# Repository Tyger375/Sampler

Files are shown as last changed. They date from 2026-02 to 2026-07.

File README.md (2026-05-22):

# Sampler

**Abstract**\
The project consists of engineering an electronic musical sampler from scratch. The work combines hardware development with the implementation of dedicated software, creating a machine equipped with pressure-sensitive pads for managing audio samples, inspired by the history of hip-hop music. This experience, balancing hobby and education, has provided solid technical skills and is conceived to be constantly updated and perfected.

Read the paper [here](https://github.com/Tyger375/Sampler/blob/main/docs/out/out.pdf) \
*made with [btex](https://github.com/Tyger375/btex)*

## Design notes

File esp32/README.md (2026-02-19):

# ESP32

Code for ESP32\
Contains:
- USB communication with slave
    - MIDI
    - CDC (Logger)
    - Vendor
- LCD 16x2 graphics
- Quantizer
- Drumpad mode
- Sequencer mode

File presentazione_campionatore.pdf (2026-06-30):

## Progettazione e Creazione di un Campionatore Elettronico

Edoardo Takanen

IIS Archimede

Edoardo Takanen (IIS Archimede) | Progettazione e Creazione di un Campionatore Elettronico | 1 / 12

## Cos’`e un Campionatore

Il campionatore (in inglese sampler) (https://www.youtube.com/watch?v=zjo7jkI8mO0) `e uno strumento musicale elettronico che `e in grado di acquisire suoni in formato digitale.

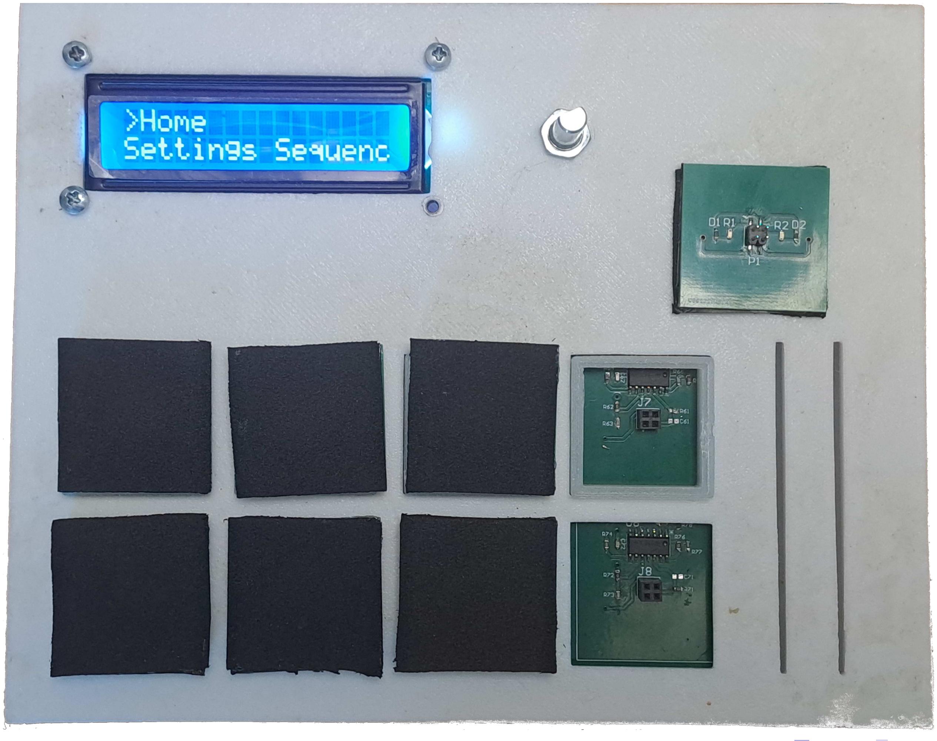
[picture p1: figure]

Edoardo Takanen (IIS Archimede) | Progettazione e Creazione di un Campionatore Elettronico | 2 / 12

## Strumentazione Utilizzata

Programmi:

KiCad
Autodesk Fusion
CLion (C++ e Rust)
MIDI-Monitor

Strumentazione e Materiali:

ESP-32 (provvisorio)
Schede elettroniche (progettate) Stagnatore + Componenti
Display LCD
Encoder rotativo
Velostat
Gomma EVA
Stampante 3D + Filamenti
(bianco e semi-trasparente)
Edoardo Takanen (IIS Archimede) | Progettazione e Creazione di un Campionatore Elettronico | 3 / 12

## Progettazione (1.0): Sensori di Pressione

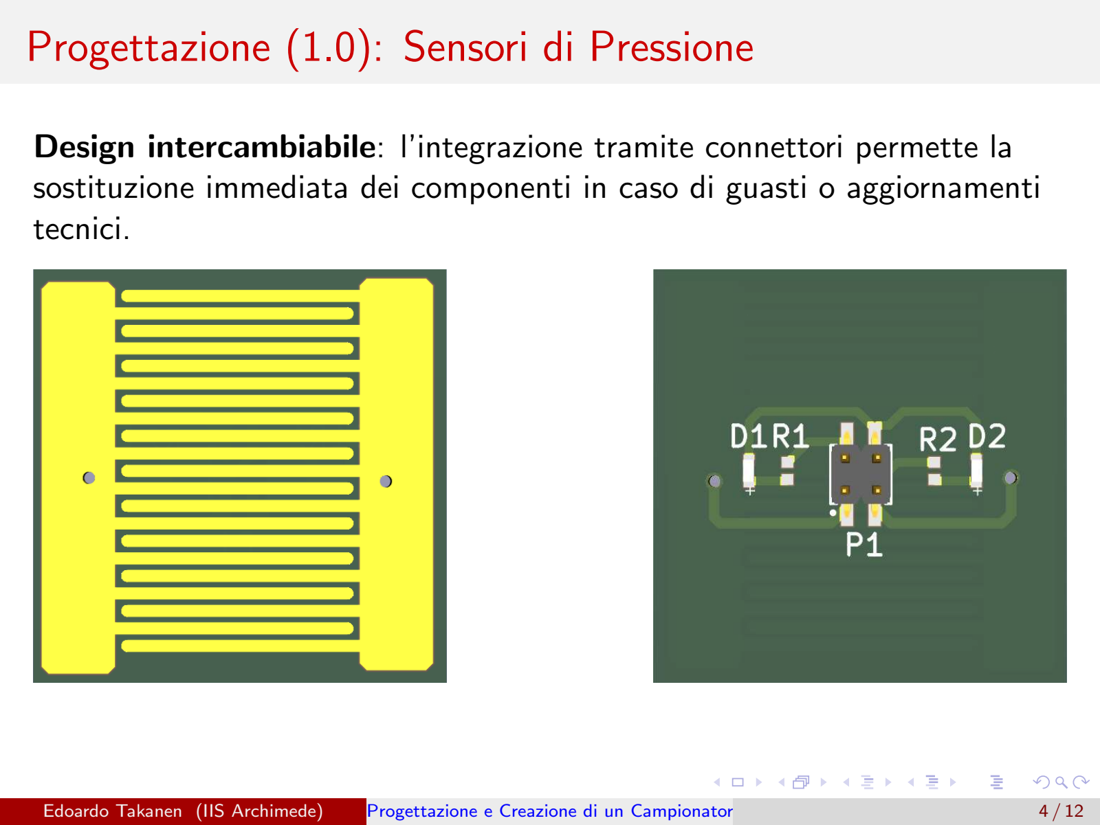
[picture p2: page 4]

Design intercambiabile: l’integrazione tramite connettori permette la sostituzione immediata dei componenti in caso di guasti o aggiornamenti tecnici.

Edoardo Takanen (IIS Archimede) | Progettazione e Creazione di un Campionatore Elettronico | 4 / 12

## Progettazione (1.1): Layering del Sensore

Il velostat a contatto con la scheda funge da resistore.
La gomma EVA ottimizza l’aderenza del sensore al pulsante.

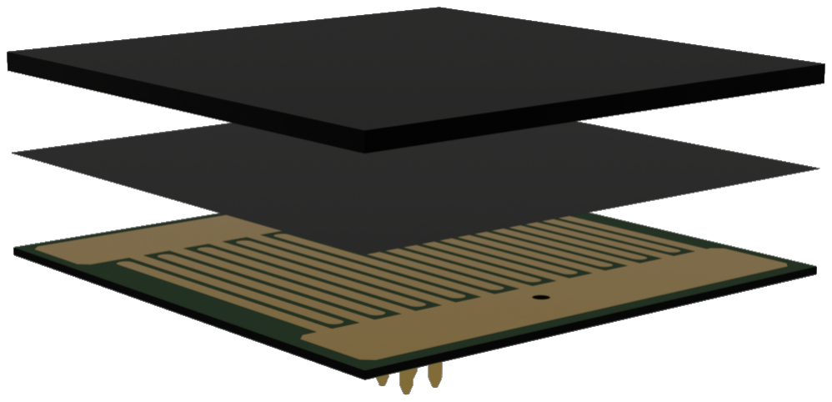
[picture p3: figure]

Edoardo Takanen (IIS Archimede) | Progettazione e Creazione di un Campionatore Elettronico | 5 / 12

## Progettazione (2.0): Supporto Sensori

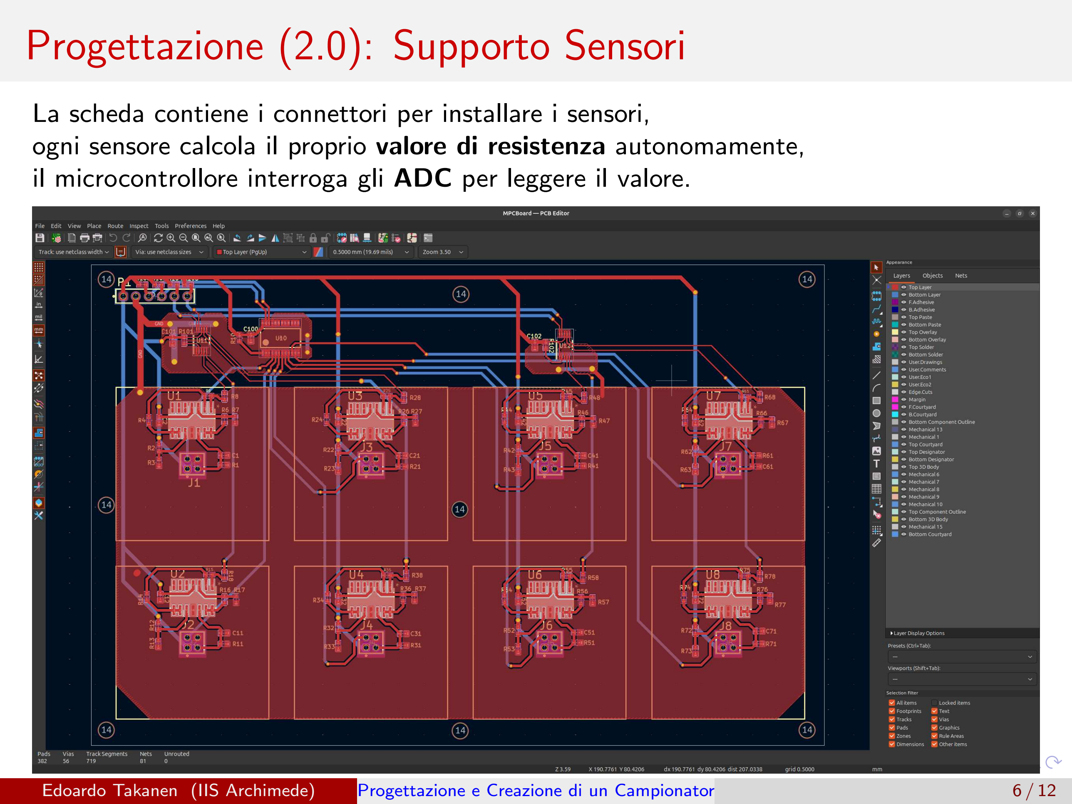
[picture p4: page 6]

La scheda contiene i connettori per installare i sensori,
ogni sensore calcola il proprio valore di resistenza autonomamente, il microcontrollore interroga gli ADC per leggere il valore.
Edoardo Takanen (IIS Archimede) | Progettazione e Creazione di un Campionatore Elettronico | 6 / 12

## Progettazione (2.1): Misurazione del valore di Resistenza

Un amplificatore da strumentazione rileva la differenza di potenziale tra i due rami del ponte di Wheatstone.

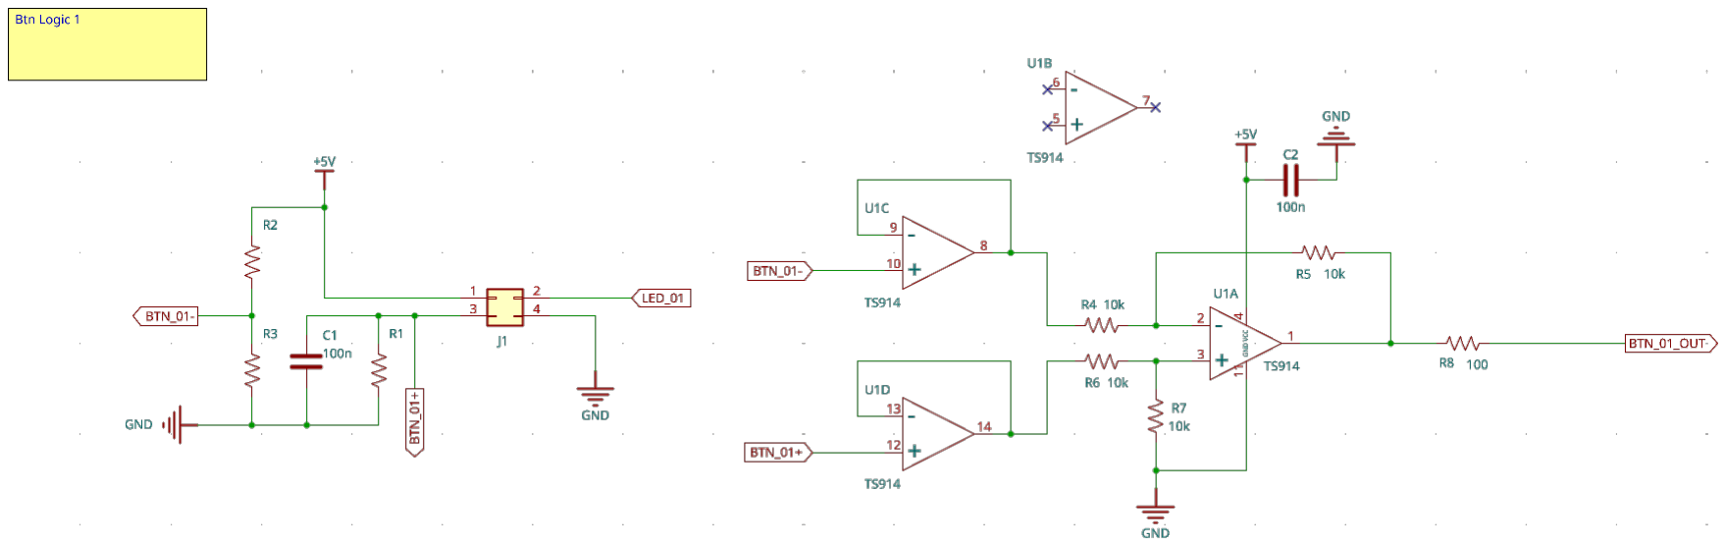
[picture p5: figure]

Edoardo Takanen (IIS Archimede) | Progettazione e Creazione di un Campionatore Elettronico | 7 / 12

## Progettazione (3.): Stampa in 3D

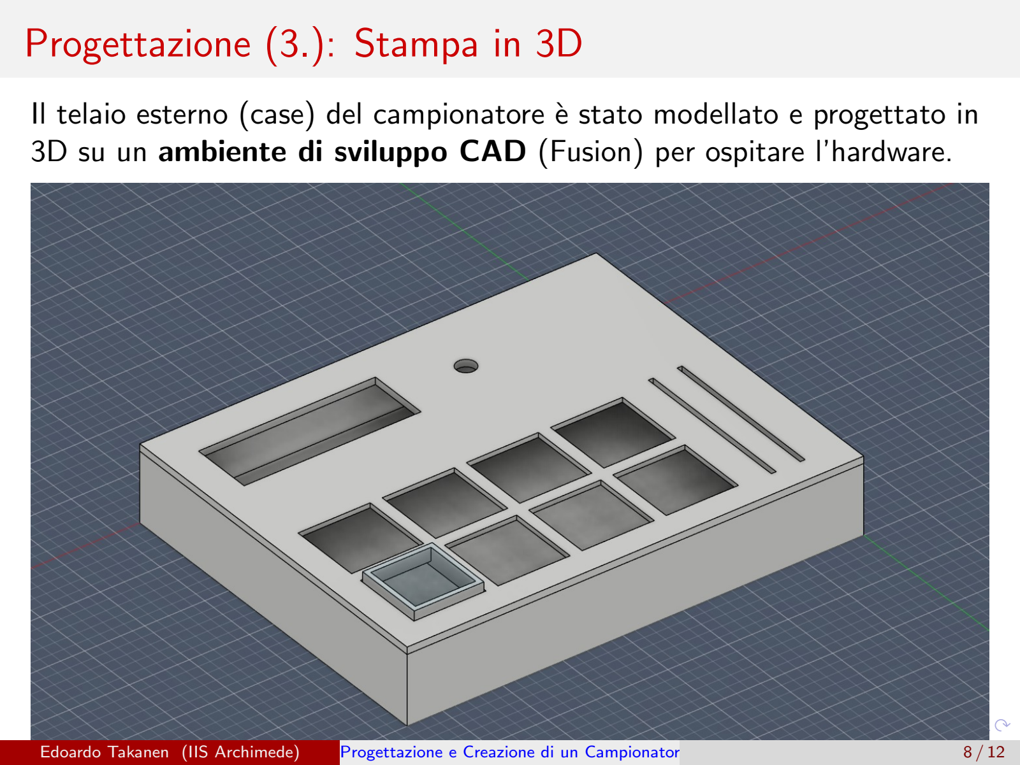
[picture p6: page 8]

Il telaio esterno (case) del campionatore `e stato modellato e progettato in 3D su un ambiente di sviluppo CAD (Fusion) per ospitare l’hardware.

Edoardo Takanen (IIS Archimede) | Progettazione e Creazione di un Campionatore Elettronico | 8 / 12

## Programmazione (4.0): Ambiente di Sviluppo

L’ESP-32 viene programmato in Rust (e C++) Gestisce:
Display LCD (I2C)
8 Pulsanti (2 ADC, I2C)
8 LED (tramite un GPIO extender, I2C)
Comunicazione USB (MIDI, CDC, Vendor) con il Master Quantizzatore
Sequenziatore
Configurazioni salvate in memoria
Edoardo Takanen (IIS Archimede) | Progettazione e Creazione di un Campionatore Elettronico | 9 / 12

## Programmazione (4.1) Il Protocollo MIDI

Ogni interazione sul controller MIDI viene convertita in un evento e inviata al Computer.
Il controller non riproduce audio, ma specifica le istruzioni musicali da far eseguire ad un sintetizzatore.

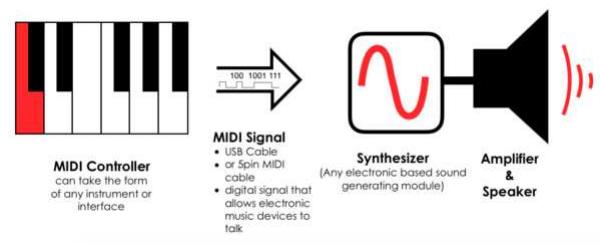
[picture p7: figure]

Edoardo Takanen (IIS Archimede) | Progettazione e Creazione di un Campionatore Elettronico | 10 / 12

## Programmazione (4.2): Quantizzatore

Allinea automaticamente le note alla griglia ritmica. Un battito (nota) `e diviso in 24 pulsazioni.

Utile per:
Sequenziatore
Sincronizzazione MIDI
Registrazione di performance
Edoardo Takanen (IIS Archimede) | Progettazione e Creazione di un Campionatore Elettronico | 11 / 12

## Programmazione (4.3): Lettura valori di pressione

Gli ADC∆Σ (Analog to Digital Converter delta-sigma) convertono costantemente i valori di resistenza.
I valori di tensione (da 0V a 5V) vengono convertiti
in valori interi a 12 bit (da 0 a 4095).
Con 3300 SPS (samples per second) una misurazione impiega circa 0.3ms.

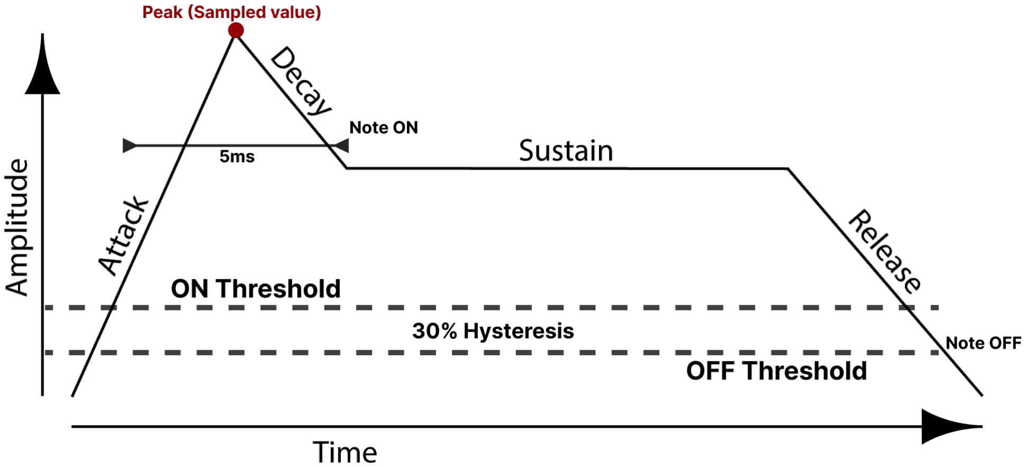
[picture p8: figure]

Edoardo Takanen (IIS Archimede) | Progettazione e Creazione di un Campionatore Elettronico | 12 / 12

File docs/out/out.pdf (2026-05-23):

# Design and Construction of a Music Sampler

Edoardo Takanen

May 23, 2026

# Introduction

A sampler is an electronic musical instrument that records and plays back samples (digital audio assets). It generally comes with a set of pressure sensitive pads, each of them can be configured to reproduce a different sample. This machine has been frequently used in hip hop music for over the past 30 years, with the Akai MPC being the most popular series of Samplers used by producers.
My goal is to engineer a custom solution from the ground up. This project was for fun as a hobby but also educational, as it required both designing the hardware and implement a dedicated software–I have learned so many new things and I definitely do not consider this project finished, but I will keep on upgrading and perfecting it.
Custom building something always comes with advantages and disadvantages. On one hand, it grants absolute control over the device, being able to implement whatever I want whenever I need some new features has a lot of different outcomes–it makes the device more flexible to future requirements. While on the other hand, there are a lot of challenges to address and options to consider, not to mention that what I am trying to imitate is something so complex that it usually takes a whole team to build–sometimes reinventing the wheel is just stressful!
Moreover, as my last year of high school, I am required to present a project that reflects my personal and technical growth throughtout this year. I believe this project fits the best for this task; compared to my previous projects, it aligns most closely with my future academic path. As I prepare to enter a five-year journey in Electronic Engineering at University, this design serves as a practical foundation for the challenges ahead.

1

## Contents

1 The Pad | 3
2 The Pads Board | 4
3 Development Tools | 6
4 Pads Management | 8
5 LedsManager | 14
6 Quantizer | 14
7 Sequencer | 18
8 Graphics | 21
9 Settings and Configurations | 25

2

## 1 The Pad

Of course the first challenge was the pressure sensitive pads. I quickly realized that there is no commercial solution that really emulates the Akai pads–my research pivoted toward custom manufacturing. I then discovered Velostat, an electrically conductive material, generally used as a packaging material, which occurs to be piezoresistive, hence, its resistance changes with pressure. Thus, each pad would consist of a PCB with exposed traces and a square of velostat pressed against the surface, the latter will connect the two traces creating a resistive path. A simple Wheatstone’s bridge will easily help us to calculate the resistance value.

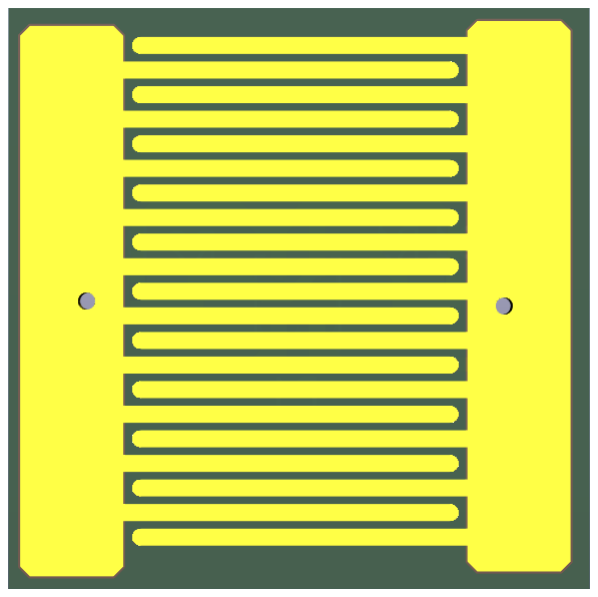
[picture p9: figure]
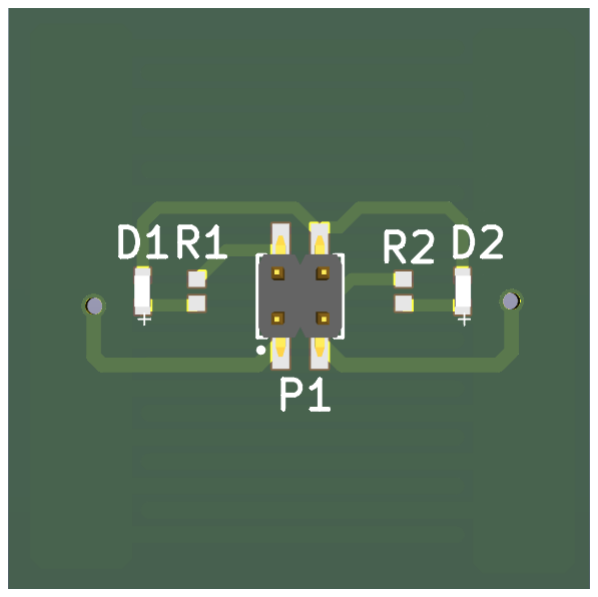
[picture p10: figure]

Furthermore, I prioritized a modular architecture. By utilizing dedicated connectors, maintenance and upgrades become seamless, allowing for the effortless replacement of individual components without affecting the entire system. Finally, I integrated LEDs to provide intuitive and instantaneous visual feedback.


The final assembly includes an uppermost layer of EVA foam, which guarantees a sufficient downward pressure to maintain solid interface between the resistive material and the conductive traces.

3

## 2 The Pads Board

After getting the pads manufactured and shipped, I needed a dedicated interface board that would handle eight buttons in place. Since MCUs hardly support eight analog pins, letting a microcontroller handle individual analog value reads and LEDs is not the optimal solutions. Hence, the board integrates external ADCs communicating via the I2C protocol.
Adopting the same modular philosophy as the pads, the architecture simplifies the interface to just six connections: a single I2C line for the ADCs, separated (in order to split the load and decrease timing issues) from another I2C line for the GPIO extender, which will control LEDs, alongside two power pins.

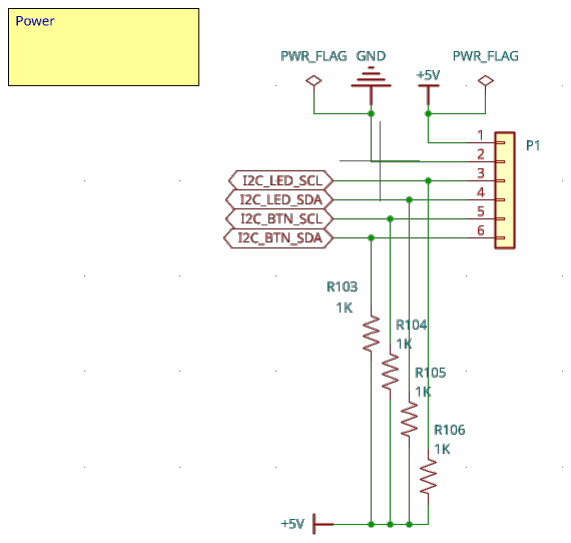
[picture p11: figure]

Figure 2: board powering

The ADS1015 is a delta-sigma analog-to-digital converter that perfectly aligns with my project requirements. With 12-bit resolution, four singleended inputs and a sampling rate of up to 3300 SPS, this component embodies all the qualities I was looking for–high convertion speed (one convertion takes approximately 0.3ms), a decent resolution (unsigned integers up to 4095) and its ability to handle four inputs via a single I2C address makes it a cost-effective and space-efficient solution for multi-channel sensing.
A Wheatstone’s bridge-based approach outputs differential signals, which the ADS1015 does support; however, this reduces the capacity to only two inputs per converter. Scaling this to eight buttons would force us to use four separate ADCs, heavily increasing delays and causing a communication bottleneck, due to the fact that they all would need to share a single I2C line. To resolve this issue, the differential signal must be processed externally before reaching the ADC. While dedicated instrumentation amplifiers are ideal for this task, as they contain low-tolerance internal resistors, which obviously means a higher unit cost. Consequently, I figured out that emulating the instrumentation amplifier myself using three common operational amplifiers was a cheaper so-

4

lution, sacrificing an ultra-high sensing precision, which was not significant for this project.
More convenient was in fact the TS914, which packages four rail-to-rail opamps, which let us keep tidiness on the board, furthermore isolating each pad, decreasing PCB complexity and maintaining a clean layout.

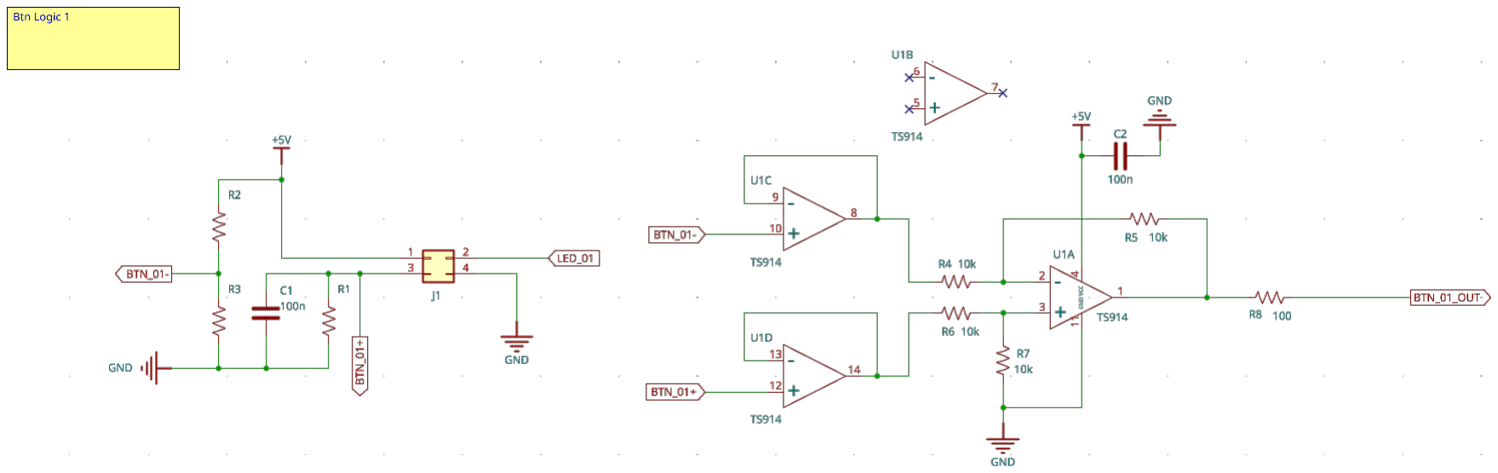
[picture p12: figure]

Figure 3: signal processing structure

Figure 3 represents the complete signal processing chain for a single pad; this architecture was subsequently replicated across all eight inputs.

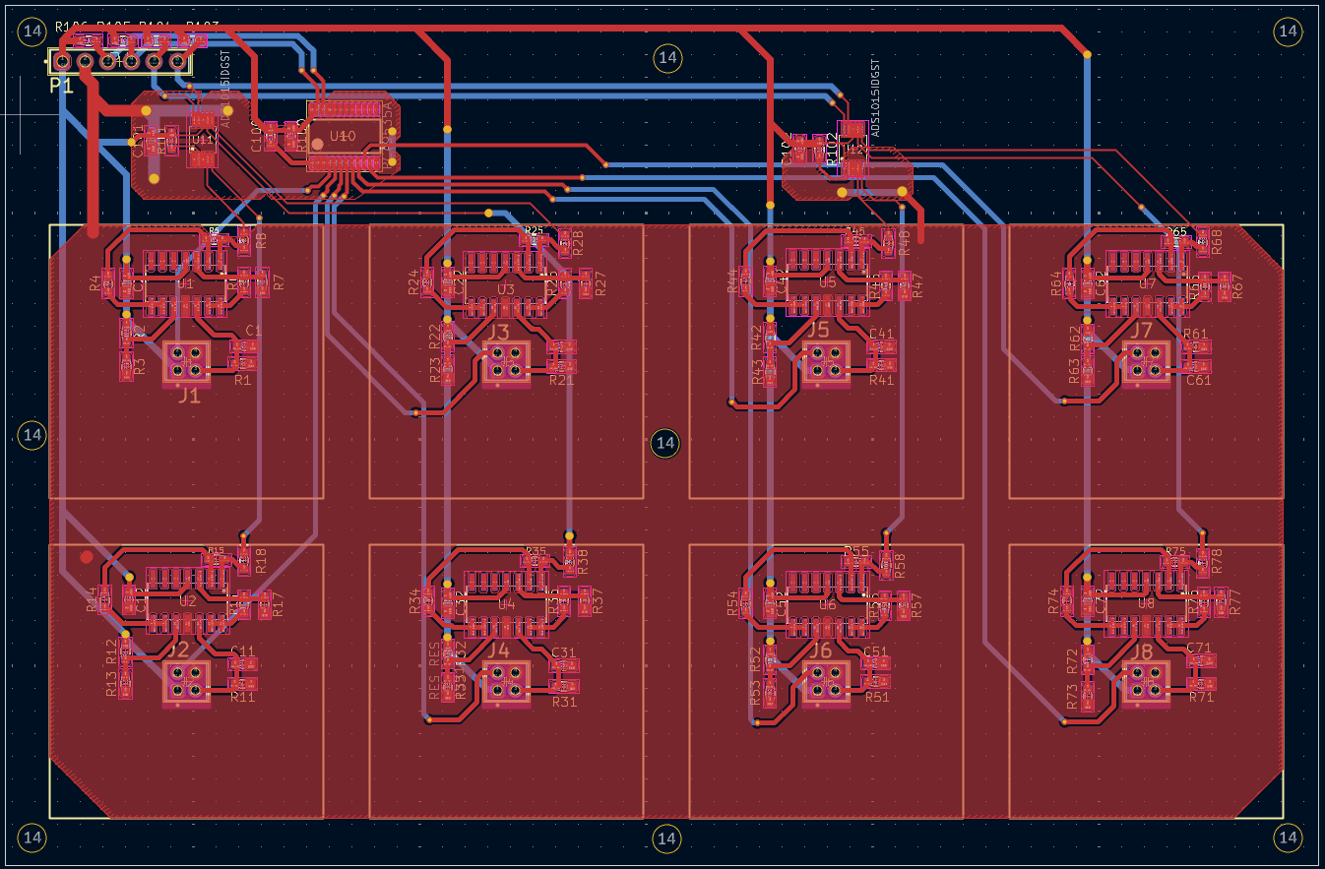
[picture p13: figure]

Figure 4: board PCB

As mentioned before, when designing the PCB, I focused on simplicity and maintaining a clean layout. Each pad is allocated a dedicated zone on the board, all the components are contained within that footprint, giving a clear visual representation of independency and isolation I was referring to.
Further information can be found inside the GitHub repository. All KiCad schematics and PCB layout fiels have been released as open-source material.

5

## 3 Development Tools

As already mentioned above, this board cannot work independently, it does not contain any processing unit that could elaborate the converted signals. Therefore this project will require another PCB to manage overall functionality of the sampler. At the time of this first draft of the paper, I still have yet to design such board, in which I plan to implement devices to allow standalone functionalities, so that no additional hardware (computers or MIDI synthesizers) is required for the instrument to work, like professional samplers.
Until the development of this final board, the only way to experiment with everything that was printed so far was to set up a breadboard environment, using an Arduino Nano ESP32 I had at home. Having already some experience with esp32 devices and their development kit, I chose the esp32s3 (the chip installed in the Arduino Nano ESP32) as a final choice for the board. Hence, the development started as a C++ project using the official espressif esp-idf framework.
Unintentionally, during this development period I was also interested in the Rust programming language and started reading the official book (https://doc.rust-lang.org/book/) just for fun and out of curiosity. I became deeply fond of the language; despite to Rust’s strict yet principled rules, transitioning from C++ was challenging but ultimately allowed me to write safer and more predictable code. As a result, I decided to utilize Rust for a real-world project for the first time. Adapting to a completely different programming language philosophy–especially Rust’s paradigm, which differs drastically from most languages–was not a seamless process, and I have yet to master it completely. Nevertheless, it proved to be an incredibly rewarding and exciting challenge, and I fully intend to continue experimenting with the language in the future.
In the GitHub repository, I decided to keep both versions of the software (folders esp32 and esp32 rust).
I opted for the esp-rs/esp-idf (https://github.com/esp-rs/esp-idf-hal) hardware abstraction layer, which does include Rust’s standard library but is not carried on officially by espressif, but rather by the community. As a result, some C++ libraries might not have been ported to Rust yet, which makes it difficult to completely migrate from C++ to Rust. This was the case for TinyUSB, an important library I was relying on to declare a composite USB device recognisable by the computer.
To fix this issue, I chose to follow esp-idf template’s (https://github.com/esp-rs/esp-idf-template) way of mixing C++ and Rust, which suggests to keep the official’s idf.py tools and C++, with the addition of a Rust static library. By using this method, I can still include esp-idf’s C++ libraries and expose methods to the Rust library, covering for what Rust’s unofficial framework has not implemented yet.

6

Thus, you can find a single C++ file that initializes USB capabilities using TinyUSB and exposes some of its functions to Rust.

1 // midi .rs

2
3 | extern "C" {
4 | // C++ defined functions
5 | fn midi_mounted () -> bool ;
6 | fn midi_out ( packet : * const [u8; 4]) ;
7 | }

8
9 pub struct MIDI ;

10
11 | // Wrapping unsafe methods
12 | impl MIDI {
13 | pub fn send ( packet : &[ u8; 4]) {
14 | unsafe {
15 | if midi_mounted () {
16 | midi_out ( packet ) ;
17 | }
18 | }
19 | }
20 | }

A primary focus during the software architecture design was achieving a high level of abstraction. Because this project is intended to be an evolving platform for long-term development, the ability to seamlessly modify and upgrade parts of the code was a must (thus, keeping that modular philosophy for both hardware and software design). Throughtout this paper, it will become evident how the codebase is divided into independent, decoupled ’libraries’– separating graphical rendering, system settings, and hardware configurations to maximize maintainability.

7

## 4 Pads Management

### 4.1 ADC Driver

As already mentioned, the pads board needs an MCU to configure the ADCs and read those resistance values. For starters, an ADS1015 driver needed to be developed. Module ads1015/mod.rs contains all the enums and methods to access and configure the ADCs via I2C communication.

1 | pub struct ADS1015 {
2 | i2c : Arc <Mutex < I2cDriver <’ static > >>,
3 | cfg_reg : AtomicU16 ,
4 | addr : u8 ,
5 | }

6
7 | impl ADS1015 {
8 | pub fn new (
9 | i2c : Arc <Mutex < I2cDriver <’ static > >>,
10 | addr : u8
11 | ) -> Self {
12 | ADS1015 {
13 | i2c ,
14 | cfg_reg : AtomicU16 :: new (0) ,
15 | addr ,
16 | }
17 | }
18 | // ...
19 | pub fn read (& self ) -> u16 {
20 | const REG_ADDR : [u8; 1] = [0 x0 ];
21 | let mut data : [u8; 2] = [0 , 0];

22
23 | {
24 | if let Ok( mut guard ) = self . i2c . lock () {
25 | guard
26 | . write_read (
27 | self . addr , & REG_ADDR , &mut data , 1000
28 | )
29 | . unwrap () ;
30 | }
31 | }

32
33 | let raw_val = (( data [0] as u16 ) << 8) | ( data [1] as u16 );
34 | raw_val >> 4
35 | }
36 | }

Recall that the two ADCs share a single I2C line, therefore, the I2cDriver also needs to be shared, which can be done safely by wrapping the struct in a std::sync::Mutex. The ADS1015 structure was designed to work securely in multi-threading environments–the only mutable variable is marked as an Atomic and all the structure’s methods work adopting the interior mutability pattern. Listing 4.1 shows how the read method fetches the latest converted value.

8

### 4.2 Pads Manager

Following with the PadsManager structure, responsible for the actual ADCs handling and reading. The instantiator creates two ADCs variables with the same configuration; the multiplexer is set to convert the first channel first, FSR (full-scale range) and data-rate are set to their maximum values, corresponding to ±6.144V (which is clamped to 5V, the supply voltage) and 3300 SPS (samples per second). The operating mode is obviously set to continuous, while the comparator is disabled.

1 | let i2c_config = I2cConfig :: new () . baudrate ( Hertz (400 _000 ));
2 | let i2c_master = I2cDriver :: new ( i2c , sda , scl , & i2c_config ) ?;

3
4 let i2c_bus = Arc :: new ( Mutex :: new ( i2c_master ) );

5
6 | let ads_cfg = ADS1015Config {
7 | mux_config : MuxConfig :: MUX0 ,
8 | fsr_mode : Fsr6_144 ,
9 | op_mode : OpModeConfig :: Continuous ,
10 | data_rate : DataRateConfig :: DataRate3300 ,
11 | comparator_mode : CompModeConfig :: Traditional ,
12 | comparator_polarity : CompPolarityConfig :: ActiveLow ,
13 | comparator_latching : CompLatchingConfig :: NonLatching ,
14 | queue_and_disable : CompQueueDisableConfig :: DisableComp ,
15 | };

16
17 | let ads1 = ADS1015 :: new ( i2c_bus . clone () , addr1 );
18 | let ads2 = ADS1015 :: new ( i2c_bus . clone () , addr2 );

19
20 | ads1 . set_config (& ads_cfg ) ?;
21 | ads2 . set_config (& ads_cfg ) ?;

9

### 4.3 Sensing Task

PadsManager’s main functionality is it’s internal task.

1 | /*
2 | name : " pads_input_task ",
3 | stack_size : 4096 ,
4 | priority : 15 ,
5 | pin_to_core : Some ( Core0 ),
6 | */

7
8 let mut channel : usize = 0;

9
10 | loop {
11 | delay_us (750) ;

12
13 | let value1 = ads1 . read () ;
14 | let value2 = ads2 . read () ;

15
16 | if let Some ( item ) = process_pad_physics ( channel as u8 , & mut
| pads_settings [ channel ], value1 ) {
17 | queue . send_back ( item , 0) . unwrap () ;
18 | };

19
20 | if let Some ( item ) = process_pad_physics (( channel as u8) + 4, &
| mut pads_settings [ channel + 4] , value2 ) {
21 | queue . send_back ( item , 0) . unwrap () ;
22 | };

23
24 | channel = ( channel + 1) % 4;

25
26 | let cfg = MuxConfig :: mux_from ( channel as u8);
27 | ads1 . set_mux (& cfg ). unwrap () ;
28 | ads2 . set_mux (& cfg ). unwrap () ;
29 | }

This is the heart of the pad sensing task (debug symbols were removed for simplicity). A task with relatively high priority (15) is pinned to the processor’s Core0 and continuously fetches ADC values and sends events to another task using FreeRTOS’s Queue.
Since a single conversion takes 0.3ms, switching channels on the multiplexer needs some time, a delay is added to prevent incorrect data from previous conversions. Switching multiplexer channels and readings from both ADCs is done almost simultaneously to save time, eight pad measurements take around 1.2ms. Moreover, software correction accounts for hardware inaccuracy and enhances the experience.

10

1 | fn process_pad_physics ( index : u8 , settings : &mut DrumPad , value :
| u16 ) -> Option < PadInputEvent > {
2 | let now = timestamp () ;
3 | const SCAN_TIME_MS : u32 = 5;
4 | const RETRIGGER_MASK_MS : u32 = 30; // Helps to debounce by
| removing noise

5
6 | match settings . state {
7 | PadState :: Idle => {
8 | if value > settings . threshold {
9 | settings . state = PadState :: Attack ;
10 | settings . peak = value ;
11 | settings . timer_start = now ;
12 | }
13 | None
14 | }
15 | PadState :: Attack => {
16 | // Update peak if sample is higher
17 | if value > settings . peak {
18 | settings . peak = value ;
19 | }

20
21 | // Wait 5ms
22 | if now - settings . timer_start >= SCAN_TIME_MS {
23 | settings . state = PadState :: Sustain ;

24
25 | let velocity = ( settings . peak >> 5) . min (127) as u8;

26
27 | Some ( PadInputEvent {
28 | index ,
29 | channel : settings . channel ,
30 | note : settings . note ,
31 | velocity : velocity ,
32 | event_type : PadInputEventType :: MIDI ( MidiType ::
| NoteOn ) ,
33 | })
34 | } else {
35 | None
36 | }
37 | }
38 | PadState :: Sustain = > {
39 | // Look for the value to drop below threshold
40 | const HYSTERESIS : f32 = 0.7;
41 | if value < ( settings . threshold as f32 * HYSTERESIS ) as
| u16 {
42 | settings . state = PadState :: Release ;
43 | settings . timer_start = now ;

44
45 | Some ( PadInputEvent {
46 | index ,
47 | channel : settings . channel ,
48 | note : settings . note ,
49 | velocity : 0,
50 | event_type : PadInputEventType :: MIDI ( MidiType ::
| NoteOff ) ,
51 | })
52 | } else {

11

53 | None
54 | }
55 | }
56 | PadState :: Release = > {
57 | if now - settings . timer_start >= RETRIGGER_MASK_MS {
58 | settings . state = PadState :: Idle ;
59 | }

60
61 | None
62 | }
63 | }
64 | }

One pad press goes throught four different stages.

1. When the state is on Idle, the program waits for a value to go above a certain threshold, which can be configured individually for each pad.
2. From that moment, the program enters the Attack state–a 5ms window is opened to look for the highest value, which will be used as the pad velocity, a NoteOn event is sent, consequently a MIDI event is transmitted to the USB host.
3. After that, the Sustain state starts, the function waits for a value to go below 70% of the configured threshold (allowing a 30% of hysteresis), a NoteOff event is sent, followed by a MIDI event.
4. Finally, the Release state waits 30ms for debouncing, preventing the pad to retrigger instantly.

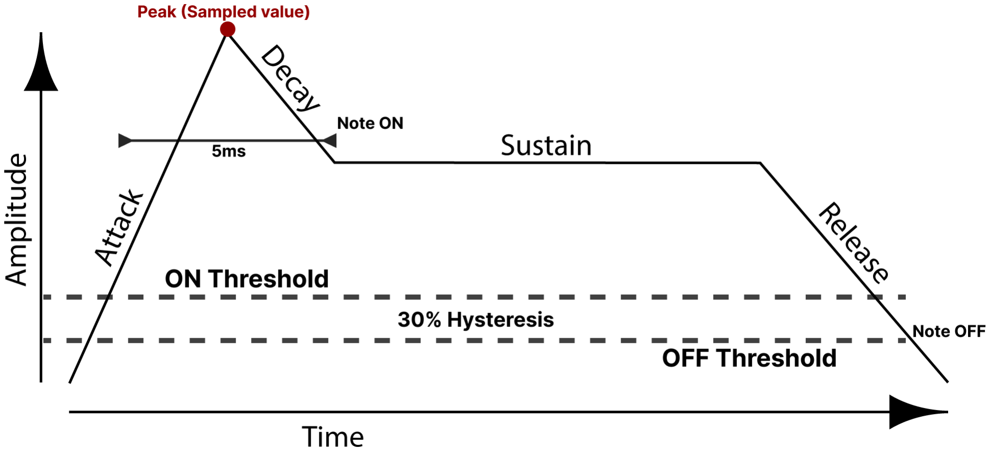
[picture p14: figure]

Figure 5: Software pads processing

12

### 4.4 Sending MIDI Events

Events that are sent to the queue are consumed by another task with a higher priority, which sends final MIDI events to the USB host, and also controls LEDs for the pads. Again, debug symbols were removed for simplicity.

1 | /*
2 | name : " pads_midi_task ",
3 | stack_size : 4096 ,
4 | priority : 23 ,
5 | pin_to_core : Some ( Core :: Core0 ),
6 | */

7
8 | loop {
9 | if let Some (( packet , _)) = queue . recv_front ( delay :: BLOCK ) {
10 | match packet . event_type {
11 | PadInputEventType :: MIDI ( midi_type ) => {
12 | let midi : (u8 , u8) = midi_type . into () ;

13
14 | if !paused . load ( Ordering :: Relaxed ) {
15 | let bytes : [u8; 4] = [ midi .0 , midi .1 | ( packet .
| channel & 0 x0F ) , packet . note , packet . velocity ];
16 | MIDI :: send (& bytes );
17 | }

18
19 | if let MidiType :: NoteOn = midi_type {
20 | leds_manager . set_led ( packet . index , true );
21 | } else if let MidiType :: NoteOff = midi_type {
22 | leds_manager . set_led ( packet . index , false );
23 | }
24 | }
25 | // ...
26 | }
27 | };
28 | }

This code enables a ’free mode’ for the drum pads, where pressing different pads sends configurable MIDI notes to the computer. By using a software sampler like TX16Wx, these MIDI events can be used to trigger and play back digital samples.

13

## 5 Quantizer

Currently, the system sends MIDI events as soon as a pad strike is sensed, ignoring the specific timing of the press. While this works for live performances, features like recording or sequencing require the program to quantize these events. By implementing a quantizer, the software can snap the timing of each note to a grid, ensuring the performance stays in sync with a set tempo. To achieve this, we define the smallest unit of time as a pulse. In a standard 4/4 time signature, a loop is divided into four beats, represented by the metronome clicks. Standard pulse resolutions typically range from 24 to 940 PPQ, pulses (or ticks) per quarter note, where a ’quarter note’ corresponds to what we earlier defined as a beat. For the development of the quantizer, it is practical to introduce an intermediate subdivision by dividing each beat (or quarter note) into four steps (1/16th notes).

Figure 6: The quantizer grid

In figure 6 the timing quantities defined by the bigger lines are the beats. Each beat is then divided into a specific PPQ amount of intervals, while the smaller lines represent what we previously called steps.
The Quantizer struct keeps count of these steps:
1 | pub struct Quantizer {
2 | pub ticks : Arc < AtomicU8 >,
3 | pub steps : Arc < AtomicU8 >,
4 | timer : TimerDriver < ’static >
5 | }

To make the system thread-safe, these shared variables are wrapped inside Arc<AtomicU8>. This atomic wrapper is crucial because it allows safe, concurrent access and modification across both the high-frequency hardware timer interrupt handler and the asynchronous quantizer main task, preventing data races without the heavy overhead of standard mutexes in an ISR (Interrupt Service Routine).
To reach a high level of precision, I am relying on the ESP32’s hardware general purpose timer. The quantizer constructor prepares the initial timing states as well as the basic configurations for this timer. To ensure the clock remains stable even when the CPU is busy with graphics or I2C communication, the highest interrupt priority is allocated to it. The base clock resolution is configurable inside the code and is tipically configured in the MegaHertz range.

14

1 | impl Quantizer {
2 | pub fn new ( notifier : Arc < Notifier >) -> Result <Self , EspError > {
3 | let ticks = Arc :: new ( AtomicU8 :: new ( TICKS_PER_STEP - 1) ) ;
4 | let steps = Arc :: new ( AtomicU8 :: new (15) );

5
6 | let mut timer_conf = TimerConfig :: default () ;
7 | timer_conf . clock_source = ClockSource :: Default ;
8 | timer_conf . direction = CountDirection :: Up ;
9 | timer_conf . resolution = Hertz ( TIMER_RESOLUTION );
10 | timer_conf . intr_priority = 3;

11
12 | let mut timer = TimerDriver :: new (& timer_conf ) ?;
13 | timer . subscribe_default () ?;
14 | timer . enable () ?;

15
16 | // ... timer interrupt

17
18 | timer . start () ?;

19
20 | Ok( Quantizer {
21 | ticks ,
22 | steps ,
23 | timer
24 | })
25 | }
26 | }

The hardware timer does not start immediately when the quantizer is instantiated because it waits for a valid BPM value to be supplied. The main software loop is responsible for retrieving this information–either loading it from a local file configuration at boot or receiving a real-time update from the display task– and passing it to the quantizer by invoking the start method. At this point, we calculate the required pulse interval (the timer step) in microseconds using the following formula:

T IMER ST EP =

60 × T IMER RESOLUT ION
BPM × P P Q | (1)

The hardware timer will thus trigger its interrupt exactly once every pulse, creating a rock-solid master clock based on the user-configurable BPM value and the chosen PPQ resolution.

1 | impl Quantizer {
2 | pub fn start (& self , bpm : u8) -> Result <() , EspError > {
3 | let time = 60 u64 * TIMER_RESOLUTION as u64;
4 | let ticks = bpm as u64 * PPQ as u64;
5 | let timer_step = time / ticks ;
6 | self . timer . set_alarm_action ( Some (& AlarmConfig {
7 | alarm_count : timer_step ,
8 | auto_reload_on_alarm : true ,
9 | reload_count : 0,
10 | .. Default :: default ()
11 | }) ) ?;
12 | Ok (() )
13 | }
14 | }

15

Note: All these parameters can be adjusted dynamically either directly from the configuration files or using the installed LCD display; we will cover the graphics engine and screen implementation later in this paper.
For simplicity, I decided to break down the timer counting into ticks (pulses) and steps, dividing a quarter note into four steps.
1 | timer . subscribe ( move |_| {
2 | let t = ticks . fetch_add (1 , Ordering :: SeqCst );
3 | if t + 1 >= TICKS_PER_STEP {
4 | ticks . store (0 , Ordering :: Relaxed ) ;
5 | let s = ( steps . load ( Ordering :: SeqCst ) + 1) % 16;
6 | steps . store (s , Ordering :: SeqCst );
7 | }

8
9 | notifier . notify_and_yield ( NonZero :: new (1) . unwrap () );
10 | }) ?;
TICKS PER STEP is just PPQ divided by 4 .
Since we are in an interrupt context, the routine needs to be quick and nonblocking. An interrupt-safe Notifier structure is used to wake up another high-priority task.
1 | /*
2 | name : " quantizer_task ",
3 | stack_size : 4096 ,
4 | priority : 24 ,
5 | pin_to_core : Some ( Core :: Core1 ),
6 | */
7 | let notification = Notification :: new () ;
8 | let quantizer = Arc :: new ( Quantizer :: new ( notification . notifier () ).
| expect (" Failed to create quantizer ") );

9
10 | const MIDI_SYNC_STEPS : u8 = PPQ / 24;
11 | const MIDI_SYNC_MSG : [u8; 4] = [0 x0F , 0 xF8 , 0 x00 , 0 x00 ];

12
13 | loop {
14 | notification . wait_any () ;
15 | if midi_sync_step == 0 {
16 | MIDI :: send (& MIDI_SYNC_MSG );
17 | }
18 | midi_sync_step = ( midi_sync_step + 1) % MIDI_SYNC_STEPS ;

19
20 | let ticks = quantizer . ticks . load ( Ordering :: SeqCst );
21 | let steps = quantizer . steps . load ( Ordering :: SeqCst );

22
23 | // notifying the quantizer
24 | if ticks == 0 {
25 | quantizer_seq_tx
26 | . send ( SequencerMessage :: NoteOn ( steps )). ok () ;
27 | } else if ticks == 5 {
28 | quantizer_seq_tx
29 | . send ( SequencerMessage :: NoteOff ( steps )) . ok () ;
30 | }
31 | }
A good practice when creating a MIDI device is to send a MIDI synchronization packet. This is a System Real-Time message used to synchronize all the

16 connected equipment. It is a single byte status message (it does not contain any data) and it must be sent 24 times per quarter note, hence it does not depend on our configured PPQ.
notification.wait any() blocks the thread and waits for a notification from the interrupt, representing a pulse being triggered. After that, a MIDI sync message is transmitted every P P Q ÷ 24 quantizer ticks and, as we will discuss later, a sequencer message is sent at the beginning (when ticks are equal to 0) and ending (last tick before a new step) of every step.

17

## 6 Sequencer

A sequencer enables the recording of a musical performance by capturing and storing note triggers relative to a master timeline. By mapping these events to specific timestamps, the sequencer can accurately reproduce the performance with consistent rhythmic integrity.
You can think of a sequencer performance as FL Studio’s channel rack, each instrument has a different programmed pattern which repeats endlessly.

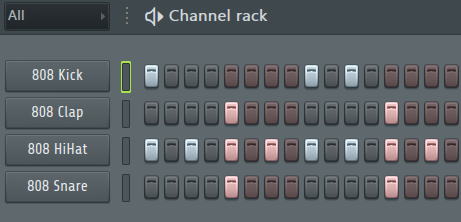
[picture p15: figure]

Figure 7: FL Studio’s Channel Rack

Thus, a sequencer project is structured as a list of tracks.

1 | pub struct SequencerTrack {
2 | pub loops : u8 ,
3 | pub resolution : SequencerResolution ,
4 | pub note : u8 ,
5 | pub triggers : Vec <u8 >,
6 | }

7
8 | pub struct SequencerProject {
9 | pub name : String ,
10 | pub loops : u8 ,
11 | pub tracks : Vec < SequencerTrack >
12 | }
While earlier we defined the largest unit of time as a loop, containing four quarter notes, a sequencer performance allows for more complex patterns with multiple loops. Each track has its own loops count, we do not need to program for four loops a simple hi-hat 2-step pattern, simply setting the project loop to 4 and track loop to 1 will do the trick. Obviously, track loop needs to be a multiple of project loop.
Notes can be programmed using the eight pads, when the Sampler is set to track programming mode, the pads LEDs stay on for set triggers, while project and tracks configurations can be edited from their screens. Since only eight pads for

18 a sequencer might not be ideal, I added a resolution parameter to each track. Resolutions range from each note representing a whole loop note, to represent a single quarter note.

1 | pub enum SequencerResolution {
2 | Quarter | = 1,
3 | HalfBeat | = 2,
4 | Beat | = 4,
5 | Loop | = 16 ,
6 | }

Mind that in this context, quarter notes and beats are not used as synonyms–I defined quarter notes as a quarter of a beat (1/16th of a loop).
The sequencer is handled by another high-priority task, which constantly waits for messages sent by the quantizer using Rust’s std::sync::mpsc::channel().
1 | /*
2 | name : " sequencer_task ",
3 | stack_size : 4096 ,
4 | priority : 23 ,
5 | pin_to_core : Some ( Core :: Core1 ),
6 | */
7 | loop {
8 | if let Ok( item ) = sequencer_channel . recv () {
9 | if sequencer . enabled () {
10 | match item {
11 | SequencerMessage :: NoteOn ( step ) => {
12 | sequencer . step_trigger_on ( step );
13 | }
14 | SequencerMessage :: NoteOff ( step ) = > {
15 | sequencer . step_trigger_off ( step );
16 | }
17 | }
18 | }
19 | }
20 | }

From this moment, the sequencer handles the triggers.

1 | pub fn step_trigger_on (& self , step : u8) {
2 | // ...
3 | for ( track , state ) in project . tracks . iter () . zip ( guard . iter_mut
() ) {
4 | let track_step = step + (16 * ( current_loop % track . loops ))
| ;
5 | Self :: handle_track_on ( track , track_step , state );
6 | }
7 | }
8 | fn handle_track_on ( track : & SequencerTrack , step : u8 , state_trigger :
| & mut bool ) {
9 | for trigger in track . triggers . iter () {
10 | let real_trigger = trigger * ( track . resolution as u8) ;
11 | if real_trigger == step {
12 | * state_trigger = true ;
13 | MIDI :: send (&[0 x09 , 0 x90 , track . note , 127]) ;
14 | }
15 | }
16 | }

19

17
18 | pub fn step_trigger_off (& self , step : u8) {
19 | // ...
20 | for ( track , state ) in project . tracks . iter () . zip ( guard . iter_mut
() ) {
21 | let track_step = step + (16 * ( current_loop % track . loops ))
| ;
22 | Self :: handle_track_off ( track , track_step , state );
23 | }

24
25 | if step == 15 {
26 | self . current_loop . store (( current_loop + 1) % project . loops ,
| Ordering :: Relaxed ) ;
27 | }
28 | }
29 | fn handle_track_off ( track : & SequencerTrack , step : u8 , state_trigger
| : & mut bool ) {
30 | for trigger in track . triggers . iter () {
31 | let real_trigger = (( trigger + 1) * ( track . resolution as u8
| )) - 1;
32 | if real_trigger == step {
33 | * state_trigger = false ;
34 | MIDI :: send (&[0 x08 , 0 x80 , track . note , 0]) ;
35 | }
36 | }
37 | }

Since track triggers are saved as pads indexes, before checking if a MIDI packet should be sent, the trigger value must be converted as a relative trigger.

Figure 8: A quantizer project example

Figure 8 shows an example of a one loop project with two tracks, emulating a simple 2-step hi-hat and snare pattern. The hi-hat pattern represented with red steps is configured with a resolution of HalfBeat and by triggering every single sequencer step on the drumpad. The snare pattern is shown colored in blue and is configured with a Beat resolution and by triggering the third pad on the first row of the drumpad.

20

## 7 Graphics

The most complex library I have written in this project is definitely the part that handles graphics. When designing such library, I aimed at some ’high’ level abstraction which would separate hardware communication from UI composition. A lot of inspiration was taken from Android’s (now) old style of building UIs and Applications–Android XML.
At the moment, I am using a text-based 16x2 LCD display, thus, the graphics library heavily relies on Rust’s String structure.
The GraphicsManager is the core of this graphics library, this structure stores screen instantiators, installs graphics drivers and handles graphics Events.
1 | pub struct GraphicsManager <’a > {
2 | drivers : Vec <Box < dyn GraphicsDriver >> ,
3 | screens_factories : HashMap <& ’ a str , Box < dyn Fn( ScreenArgs ) ->
| Box < dyn Screen >>>,
4 | current_screen : Option <(& ’ a str , Box < dyn Screen >) >,
5 | backstack : Vec <& ’ a str >
6 | }

This graphics set of utilities relies on graphics Events, a screen is only refreshed when an update is sent. Events are sent from hardware controls, like pads pressing, controller movements etc.

1 | pub enum GraphicsEvent {
2 | Click ,
3 | Back ,

4
5 | ScrollLeft ,
6 | ScrollRight ,

7
8 | ScreenStart ,
9 | ScreenEnd ,

10
11 | Refresh ( String )
12 | }

Graphics events are sent by the graphics manager to the current screen, which will dispatch them to the focused UIElement.

21

### 7.1 Screen

UIs are built on screens, which can be compared to Android’s Activities. Default method implementations are omitted for simplicity.

1 | pub struct ScreenData {
2 | pub elements : Vec <Box < dyn UIElement >>,
3 | pub row_offset : usize ,
4 | pub focus : bool
5 | }

6
7 | pub trait Screen {
8 | fn get_data (& self ) -> & ScreenData ;
9 | fn get_data_mut (& mut self ) -> & mut ScreenData ;

10
11 | fn on_start (& mut self );
12 | fn on_end (& mut self );

13
14 | fn on_click (& mut self );
15 | fn on_back (& mut self ) -> bool ;
16 | fn on_scroll (& mut self , direction : bool );

17
18 | fn on_custom_event (& mut self , _event : u32 ) -> bool ;

19
20 | fn refresh (& mut self , _message : String ) ;
21 | fn render (& self , selector_press : bool ) -> Vec < String >;
22 | }

A screen can contain different UIElements, like texts, buttons etc.
At startup, the main thread loads the GraphicsManager with all the screen instantiators (initializers). The instantiators are summoned when required.
1 | pub fn load_screen <F >(& mut self , id: &’a str , factory : F )
2 | where F: Fn( ScreenArgs ) -> Box < dyn Screen > + ’static {
3 | self . screens_factories . insert (id , Box :: new ( factory )) ;
4 | }

5
6 | fn navigate_screen (& mut self , id: &’a str , mut screen : Box < dyn
| Screen >) {
7 | if let Some ( current_screen ) = self . current_screen . as_mut () {
8 | current_screen .1. on_end () ;
9 | }

10
11 | screen . on_start () ;
12 | self . current_screen = Some ((id , screen )) ;
13 | }

14
15 | pub fn navigate (& mut self , id: &str , _args : Vec < String >) {
16 | let (id , factory ) = self . screens_factories . get_key_value (id).
| expect (" Couldn ’t find screen ");

17
18 | if let Some ( current_screen ) = self . current_screen . as_mut () {
19 | self . backstack . push ( current_screen .0) ;
20 | }

21
22 | self . navigate_screen (id , factory ( None ) );
23 | }

22

### 7.2 UIElement

A UIElement takes a whole line on the LCD, a render method returns the text to render on screen, an on event method handles events to consume graphics interactions, a boolean value is returned to specify if the component requires internal focus.

1 | pub trait UIElement {
2 | fn render (& self , state : UIElementState ) -> String ;

3
4 | fn on_event (& mut self , _event : GraphicsEvent ) -> bool {
5 | false
6 | }
7 | }

Below, the button component is reported as an example.

1 | pub struct UIButton {
2 | text : String ,
3 | on_click : Box < dyn Fn () >
4 | }

5
6 | impl UIButton {
7 | pub fn new <F >( text : String , on_click : F) -> Self
8 | where F: Fn () + ’static {
9 | UIButton {
10 | text ,
11 | on_click : Box :: new ( on_click )
12 | }
13 | }
14 | }

15
16 | impl UIElement for UIButton {
17 | fn render (& self , state : UIElementState ) -> String {
18 | let prefix = match state {
19 | UIElementState :: Selected => ">",
20 | UIElementState :: SelectorPress => "\\",
21 | UIElementState :: None => ""
22 | };
23 | format! (" {}{} ", prefix , self . text )
24 | }

25
26 | fn on_event (& mut self , event : GraphicsEvent ) -> bool {
27 | match event {
28 | GraphicsEvent :: Click => {
29 | ( self . on_click ) () ;
30 | false
31 | }
32 | _ => false ,
33 | }
34 | }
35 | }

23

### 7.3 Rendering and Graphics Drivers

As mentioned before, display refreshes are triggered only when needed. The GraphicsManager calls the current screen’s render function, which iterates throught two on-screen components and invokes their render methods. After that, the manager iterates throught installed graphics drivers and sends those returned strings for rendering.

1 | pub trait GraphicsDriver {
2 | fn init (& mut self ) ;
3 | fn draw (& mut self , rows : &Vec <String >) ;
4 | fn clear (& mut self );
5 | }

When developing this graphics library, I opted for an almost completely abstract approach, so that future changes or updates will result easy and effortless.

24

## 8 Settings and Configurations

As I mentioned earlier, one of my main goals when structuring this project was abstraction. Because I want to keep updating and expanding this project over the next few years, I couldn’t just hardcode configurations or dump everything into a single file. I needed a system where parts of the code could be seamlessly swapped or upgraded without breaking the rest of the software.
To achieve this, I built a component-based configuration engine from scratch. It uses the ESP-IDF virtual filesystem (VFS) to talk to a dedicated flash memory partition formatted with LittleFS (which is perfect for embedded microcontrollers because it handles sudden power cuts safely).
The core of this system is the SettingsManager, which acts as a central coordinator for different modules like graphics, MIDI mappings, or pad sensitivities. Storing different kinds of configuration modules in a single place is a classic programming challenge. A ”MIDI Component” needs completely different variables than a ”Graphics Component,” but the central manager needs to treat them all uniformly.
In C++, this can be solved with unsafe pointer casting (void*), but coming to Rust forced me to think differently. I implemented a thread-safe, polymorphic architecture using a HashMap wrapped inside a Mutex:
1 | components : Mutex < HashMap <& ’ static str , Box < dyn SettingsComponent
| >>>
By using a dynamic trait object (Box), the manager can store any module that implements my SettingsComponent trait.
When a specific part of the system needs to read its parameters, it retrieves the component and uses runtime downcasting via Rust’s std::any::Any trait to safely recover the original, concrete layout:
1 | pub fn add_component <T , F >(& self , id: &’ static str , f : F)
2 | where T: SettingsComponent , F: FnOnce ( Sender <C >) -> T {
3 | let mut components = self . components . lock () . unwrap () ;
4 | components . insert (id , Box :: new (f( self . tx . clone () )));
5 | }

6
7 | pub fn get_component <T , F , R >(
8 | &self ,
9 | id: &str ,
10 | f: F
11 | ) -> Option <R >
12 | where T: SettingsComponent , F: FnOnce (& T) -> R ,
13 | {
14 | let components = self . components . lock () . unwrap () ;
15 | components . get (id). and_then (| boxed | {
16 | boxed . as_any () . downcast_ref :: <T >()
17 | }) . map ( f)
18 | }

What I love about this pattern is that the main manager doesn’t need to know what data is inside each component. It just acts as a storage locker, keeping the code beautifully decoupled.

25

For saving data permanently onto the ESP32’s flash memory, I used the Serde framework to handle serialization, storing everything in human-readable TOML files. Since manual file editing or software updates can sometimes introduce bugs or corrupt files, I knew I needed a fallback mechanism. I wrote a helper function utilizing Rust’s Default trait to ensure the device never crashes (panics) due to a missing or corrupted file at boot:

1 | pub fn load_config_or_default <T >( path : & str ) -> T
2 | where T: Serialize + DeserializeOwned + Default {
3 | if let Ok( content ) = fs :: read_to_string ( path ) {
4 | if let Ok( config ) = toml :: from_str :: <T >(& content ) {
5 | return config ;
6 | }
7 | }
8 | // Fallback : If the file is missing or broken , create a default
| one on the fly
9 | let default_conf = T :: default () ;
10 | save_config ( path , & default_conf );
11 | default_conf
12 | }

If a configuration file is missing, the system catches the error, generates a clean set of defaults, writes it back to the storage partition, and keeps running smoothly.
Finally, to handle communication between different parts of the system without running into the strict memory access rules enforced by Rust’s borrow checker, I integrated a std::sync::mpsc channel.
When a new component is attached via add component, it receives a cloned transmitter (Sender). This allows isolated background tasks to safely send real-time configuration updates back to the main control thread asynchronously, keeping the entire application organized and responsive.
1 | pub fn add_component <T , F >(& self , id: &’ static str , f : F)
2 | where
3 | T: SettingsComponent ,
4 | F: FnOnce ( Sender <C >) -> T {
5 | let mut components = self . components . lock () . unwrap () ;
6 | components . insert (id , Box :: new (f( self . tx . clone () )));
7 | }

SettingsManager’s interior mutability allows the structure to be wrapped into a std::sync::Arc and to be securely passed to multiple threads.

26

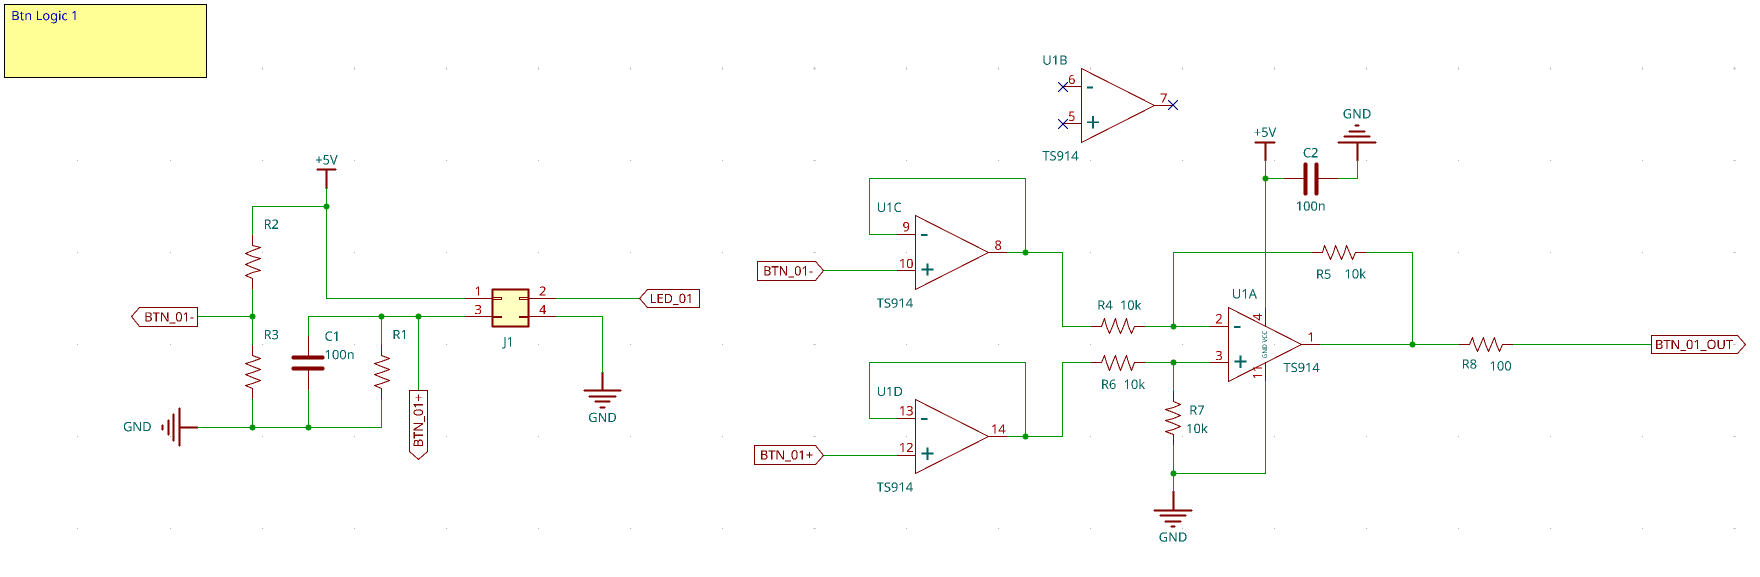
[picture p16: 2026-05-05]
docs/images/board-schematic.png

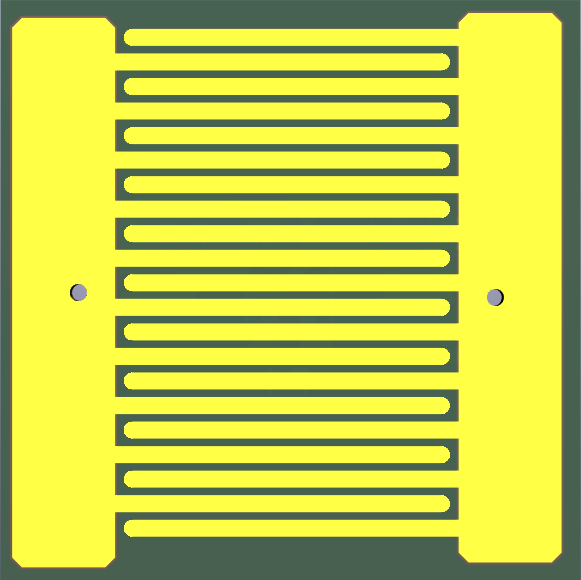
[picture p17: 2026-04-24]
docs/images/button-front.png

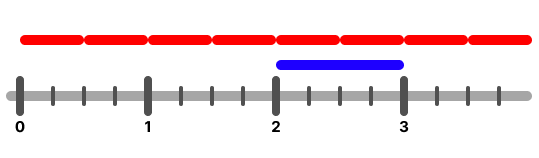
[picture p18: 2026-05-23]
docs/images/quantizer-project.png

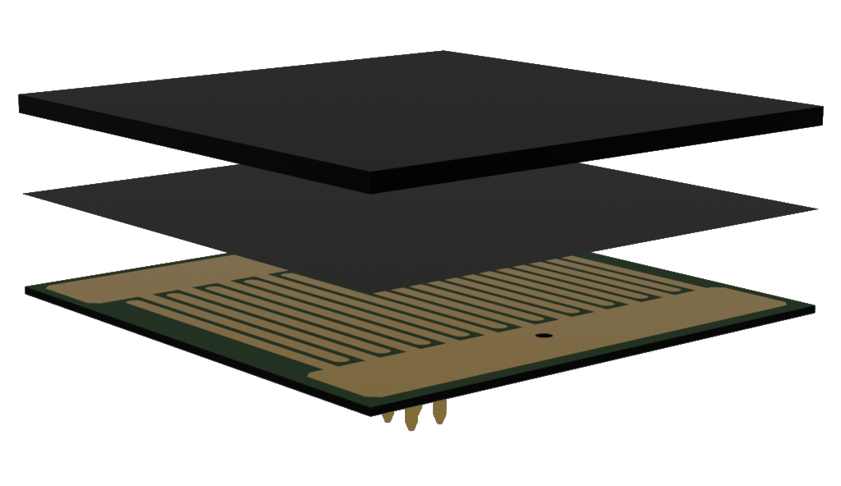
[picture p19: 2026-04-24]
docs/images/button.png

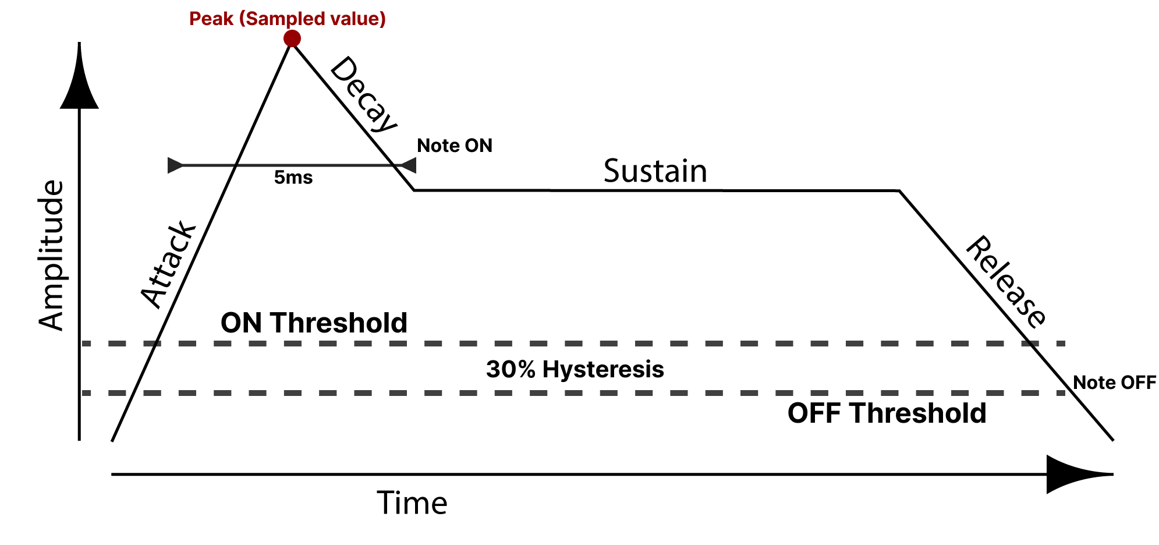
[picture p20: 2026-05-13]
docs/images/pads-processing.png

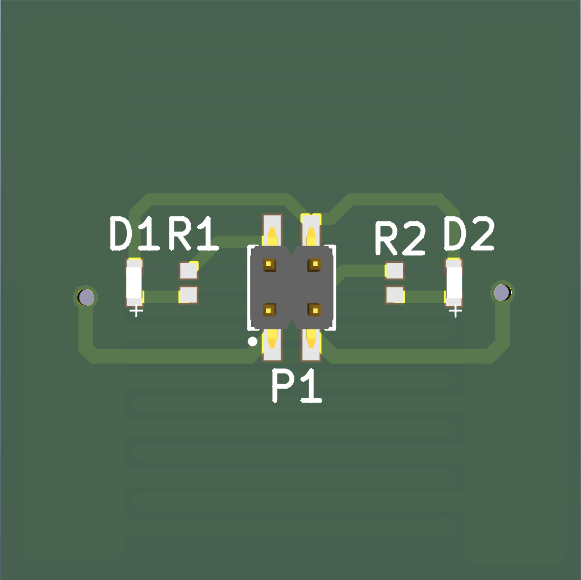
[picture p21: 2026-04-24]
docs/images/button-back.png

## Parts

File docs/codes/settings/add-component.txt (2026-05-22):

pub fn add_component<T, F>(&self, id: &'static str, f: F)
where
    T: SettingsComponent,
    F: FnOnce(Sender<C>) -> T {
    let mut components = self.components.lock().unwrap();
    components.insert(id, Box::new(f(self.tx.clone())));
}

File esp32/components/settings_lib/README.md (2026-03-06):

# Settings Library

Abstract layer made to handle persistent configurations

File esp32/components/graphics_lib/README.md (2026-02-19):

# Graphics Library

Little **text-only** graphics library to easily handle screens and UI components\
_Inspired by Android's Activity structure_

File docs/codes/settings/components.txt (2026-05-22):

components: Mutex<HashMap<&'static str, Box<dyn SettingsComponent>>>

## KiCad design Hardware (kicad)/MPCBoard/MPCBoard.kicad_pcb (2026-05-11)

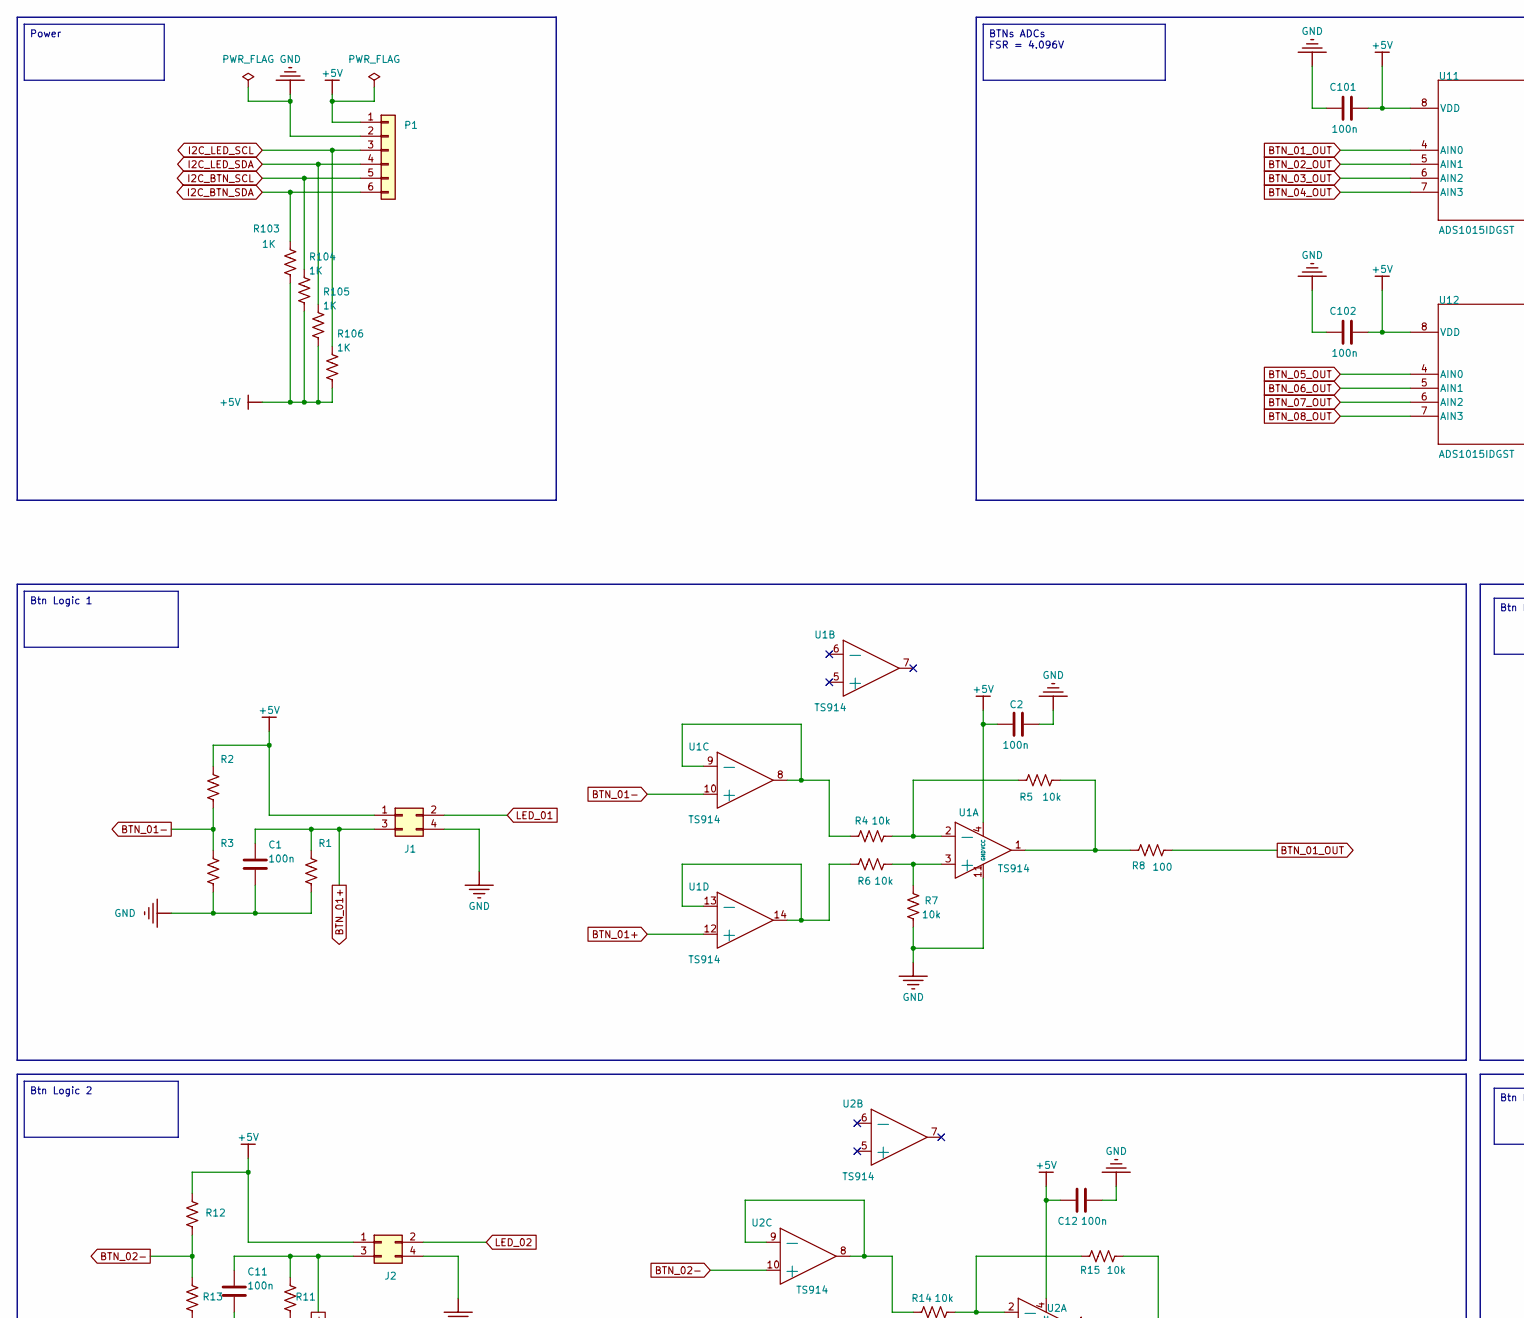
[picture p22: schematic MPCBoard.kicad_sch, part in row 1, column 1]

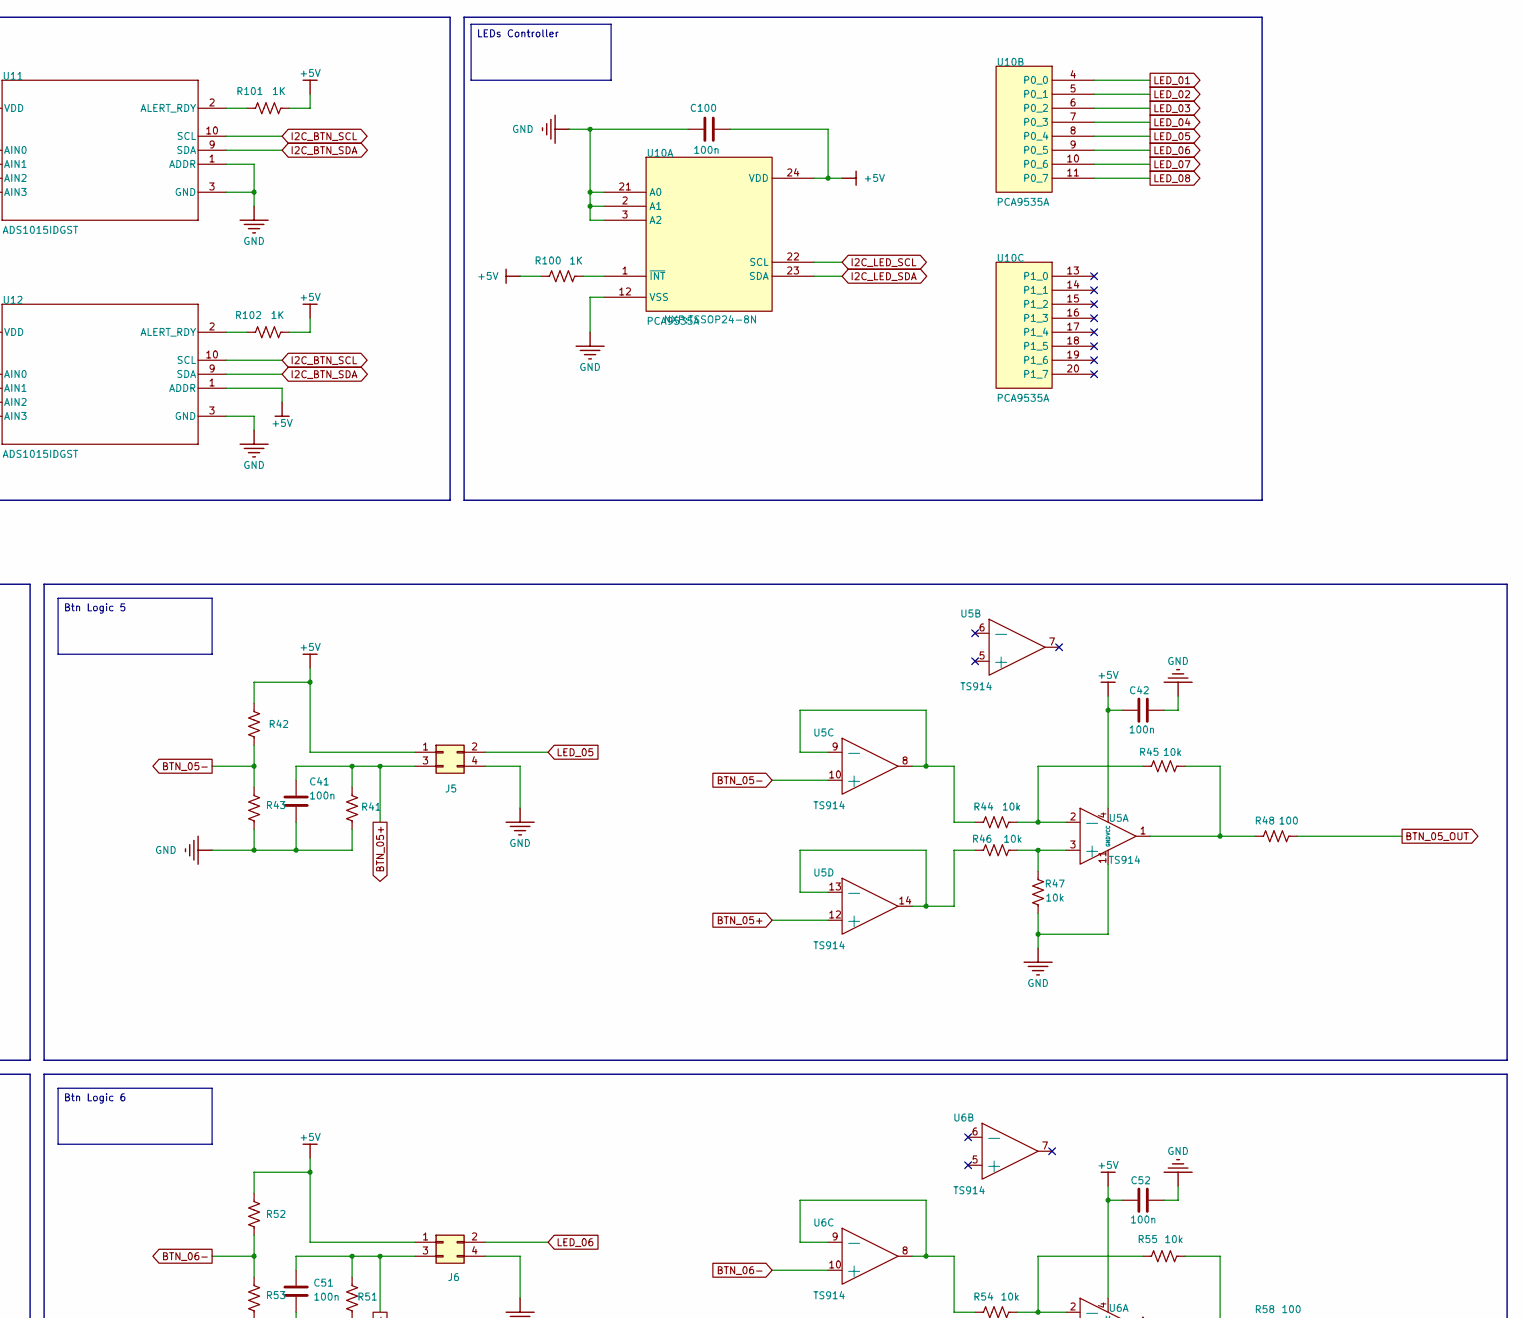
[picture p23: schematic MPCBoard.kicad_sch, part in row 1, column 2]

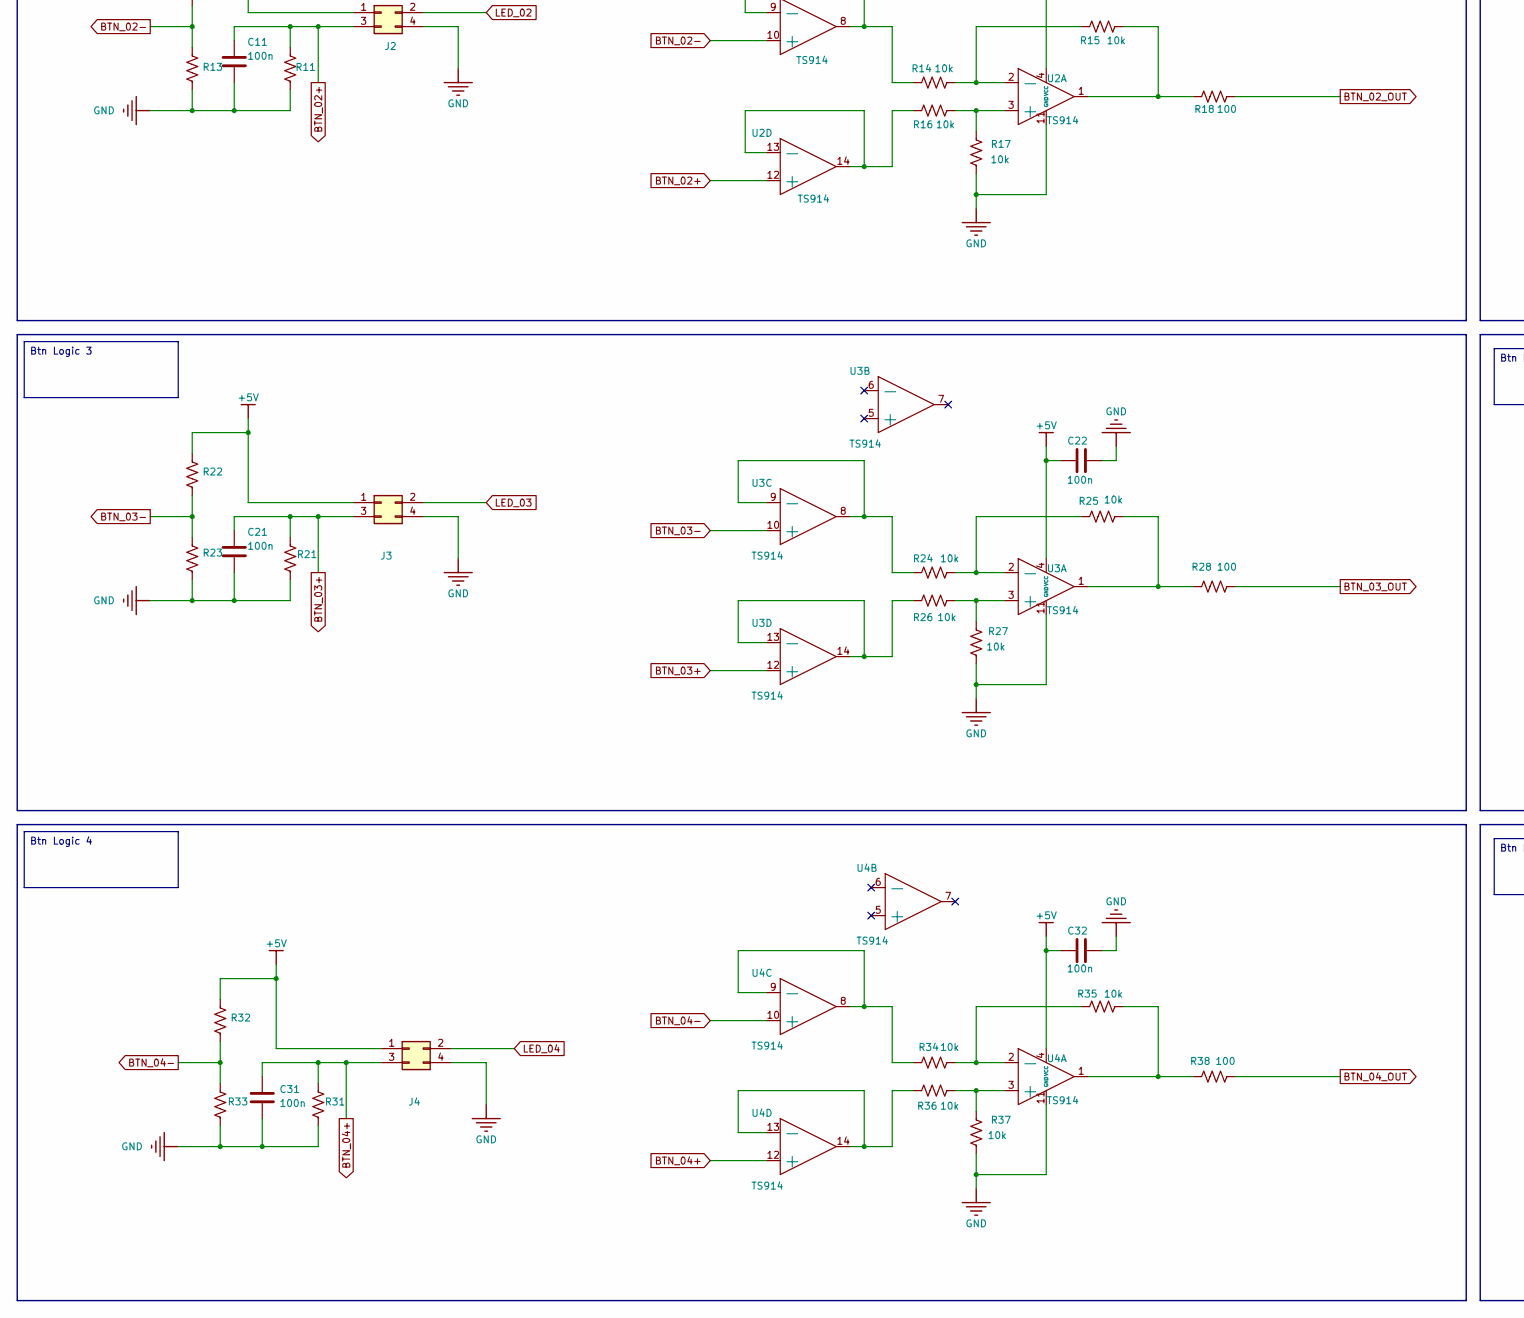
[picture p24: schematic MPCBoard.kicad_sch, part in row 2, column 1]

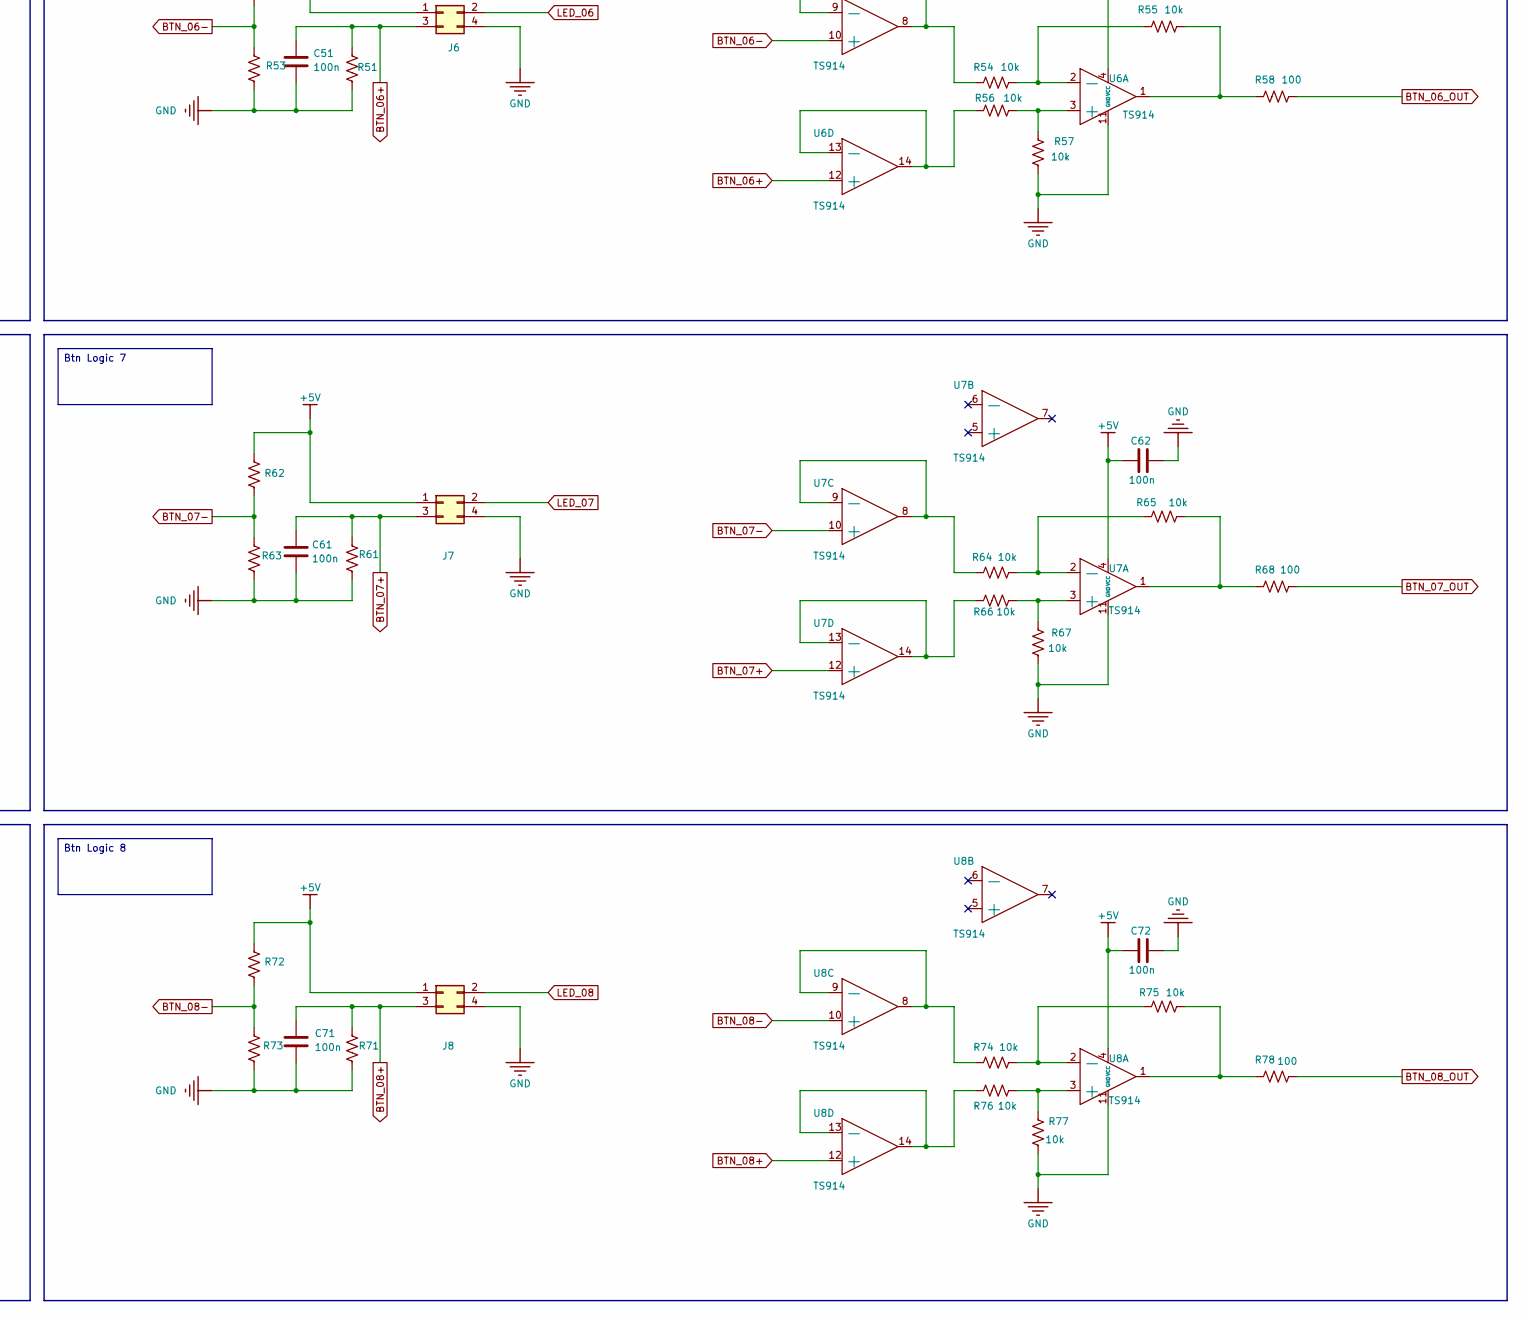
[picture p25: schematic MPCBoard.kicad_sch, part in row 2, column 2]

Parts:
C1, C2, C11, C12, C21, C22, C31, C32, C41, C42, C51, C52, C61, C62, C71, C72, C100, C101, C102: 100n; C_0603_1608Metric_Pad1.08x0.95mm_HandSolder
J1, J2, J3, J4, J5, J6, J7, J8: 62000421821; WORKING VOLTAGE 250V; WITHSTANDING VOLTAGE 500V; MANUFACTURER PART NUMBER 62000421821
P1: 61300611121; WORKING VOLTAGE 250V; WITHSTANDING VOLTAGE 500V; MANUFACTURER PART NUMBER 61300611121
R1, R2, R3, R11, R12, R13, R21, R22, R23, R31, R32, R33, R41, R42, R43, R51, R52, R53, R61, R62, R63, R71, R72, R73: RES; R_0603_1608Metric_Pad0.98x0.95mm_HandSolder
R4, R5, R6, R7, R14, R15, R16, R17, R24, R25, R26, R27, R34, R35, R36, R37, R44, R45, R46, R47, R54, R55, R56, R57, R64, R65, R66, R67, R74, R75, R76, R77: 10k; R_0603_1608Metric_Pad0.98x0.95mm_HandSolder
R8, R18, R28, R38, R48, R58, R68, R78: 100; R_0603_1608Metric_Pad0.98x0.95mm_HandSolder
R100, R101, R102, R103, R104, R105, R106: 1K; R_0603_1608Metric_Pad0.98x0.95mm_HandSolder
U1, U2, U3, U4, U5, U6, U7, U8: TS914; TS914IDT
U10: PCA9535A; TSSOP24-8N
U11, U12: ADS1015IDGST; SOP50P490X110-10N; MANUFACTURER_PART_NUMBER ADS1015IDGST

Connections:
+5V: C2.1, C12.1, C22.1, C32.1, C42.1, C52.1, C62.1, C72.1, C100.2, C101.2, C102.2, J1.1, J2.1, J3.1, J4.1, J5.1, J6.1, J7.1, J8.1, P1.1, R2.1, R12.1, R22.1, R32.1, R42.1, R52.1, R62.1, R72.1, R100.1, R101.2, R102.2, R103.2, R104.2, R105.2, R106.2, U1.4 (VCC), U2.4 (VCC), U3.4 (VCC), U4.4 (VCC), U5.4 (VCC), U6.4 (VCC), U7.4 (VCC), U8.4 (VCC), U10.24 (VDD), U11.8 (VDD), U12.1 (ADDR), U12.8 (VDD)
BTN_01+: C1.1, J1.3, R1.1, U1.12 (+)
BTN_01-: R2.2, R3.1, U1.10 (+)
BTN_01_OUT: R8.2, U11.4 (AIN0)
BTN_02+: C11.1, J2.3, R11.1, U2.12 (+)
BTN_02-: R12.2, R13.1, U2.10 (+)
BTN_02_OUT: R18.2, U11.5 (AIN1)
BTN_03+: C21.1, J3.3, R21.1, U3.12 (+)
BTN_03-: R22.2, R23.1, U3.10 (+)
BTN_03_OUT: R28.2, U11.6 (AIN2)
BTN_04+: C31.1, J4.3, R31.1, U4.12 (+)
BTN_04-: R32.2, R33.1, U4.10 (+)
BTN_04_OUT: R38.2, U11.7 (AIN3)
BTN_05+: C41.1, J5.3, R41.1, U5.12 (+)
BTN_05-: R42.2, R43.1, U5.10 (+)
BTN_05_OUT: R48.2, U12.4 (AIN0)
BTN_06+: C51.1, J6.3, R51.1, U6.12 (+)
BTN_06-: R52.2, R53.1, U6.10 (+)
BTN_06_OUT: R58.2, U12.5 (AIN1)
BTN_07+: C61.1, J7.3, R61.1, U7.12 (+)
BTN_07-: R62.2, R63.1, U7.10 (+)
BTN_07_OUT: R68.2, U12.6 (AIN2)
BTN_08+: C71.1, J8.3, R71.1, U8.12 (+)
BTN_08-: R72.2, R73.1, U8.10 (+)
BTN_08_OUT: R78.2, U12.7 (AIN3)
GND: C1.2, C2.2, C11.2, C12.2, C21.2, C22.2, C31.2, C32.2, C41.2, C42.2, C51.2, C52.2, C61.2, C62.2, C71.2, C72.2, C100.1, C101.1, C102.1, J1.4, J2.4, J3.4, J4.4, J5.4, J6.4, J7.4, J8.4, P1.2, R1.2, R3.2, R7.2, R11.2, R13.2, R17.2, R21.2, R23.2, R27.2, R31.2, R33.2, R37.2, R41.2, R43.2, R47.2, R51.2, R53.2, R57.2, R61.2, R63.2, R67.2, R71.2, R73.2, R77.2, U1.11 (GND), U2.11 (GND), U3.11 (GND), U4.11 (GND), U5.11 (GND), U6.11 (GND), U7.11 (GND), U8.11 (GND), U10.2 (A1), U10.3 (A2), U10.12 (VSS), U10.21 (A0), U11.1 (ADDR), U11.3 (GND), U12.3 (GND)
I2C_BTN_SCL: P1.5, R104.1, U11.10 (SCL), U12.10 (SCL)
I2C_BTN_SDA: P1.6, R103.1, U11.9 (SDA), U12.9 (SDA)
I2C_LED_SCL: P1.3, R106.1, U10.22 (SCL)
I2C_LED_SDA: P1.4, R105.1, U10.23 (SDA)
LED_01: J1.2, U10.4 (P0_0)
LED_02: J2.2, U10.5 (P0_1)
LED_03: J3.2, U10.6 (P0_2)
LED_04: J4.2, U10.7 (P0_3)
LED_05: J5.2, U10.8 (P0_4)
LED_06: J6.2, U10.9 (P0_5)
LED_07: J7.2, U10.10 (P0_6)
LED_08: J8.2, U10.11 (P0_7)
unnamed: R5.2, R8.1, U1.1
unnamed: R15.2, R18.1, U2.1
unnamed: R25.2, R28.1, U3.1
unnamed: R35.2, R38.1, U4.1
unnamed: R45.2, R48.1, U5.1
unnamed: R55.2, R58.1, U6.1
unnamed: R65.2, R68.1, U7.1
unnamed: R75.2, R78.1, U8.1
unnamed: R6.2, R7.1, U1.3 (+)
unnamed: R4.2, R5.1, U1.2 (-)
unnamed: R4.1, U1.8, U1.9 (-)
unnamed: R6.1, U1.13 (-), U1.14
unnamed: R16.2, R17.1, U2.3 (+)
unnamed: R14.2, R15.1, U2.2 (-)
unnamed: R14.1, U2.8, U2.9 (-)
unnamed: R16.1, U2.13 (-), U2.14
unnamed: R26.2, R27.1, U3.3 (+)
unnamed: R24.2, R25.1, U3.2 (-)
unnamed: R24.1, U3.8, U3.9 (-)
unnamed: R26.1, U3.13 (-), U3.14
unnamed: R36.2, R37.1, U4.3 (+)
unnamed: R34.2, R35.1, U4.2 (-)
unnamed: R34.1, U4.8, U4.9 (-)
unnamed: R36.1, U4.13 (-), U4.14
unnamed: R46.2, R47.1, U5.3 (+)
unnamed: R44.2, R45.1, U5.2 (-)
unnamed: R44.1, U5.8, U5.9 (-)
unnamed: R46.1, U5.13 (-), U5.14
unnamed: R56.2, R57.1, U6.3 (+)
unnamed: R54.2, R55.1, U6.2 (-)
unnamed: R54.1, U6.8, U6.9 (-)
unnamed: R56.1, U6.13 (-), U6.14
unnamed: R66.2, R67.1, U7.3 (+)
unnamed: R64.2, R65.1, U7.2 (-)
unnamed: R64.1, U7.8, U7.9 (-)
unnamed: R66.1, U7.13 (-), U7.14
unnamed: R76.2, R77.1, U8.3 (+)
unnamed: R74.2, R75.1, U8.2 (-)
unnamed: R74.1, U8.8, U8.9 (-)
unnamed: R76.1, U8.13 (-), U8.14
unnamed: R100.2, U10.1 (~INT)
unnamed: R101.1, U11.2 (ALERT_RDY)
unnamed: R102.1, U12.2 (ALERT_RDY)

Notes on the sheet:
Btn Logic 3
BTNs ADCs FSR = 4.096V
Btn Logic 1
Power
Btn Logic 6
Btn Logic 7
Btn Logic 5
Btn Logic 4
Btn Logic 8
Btn Logic 2
LEDs Controller

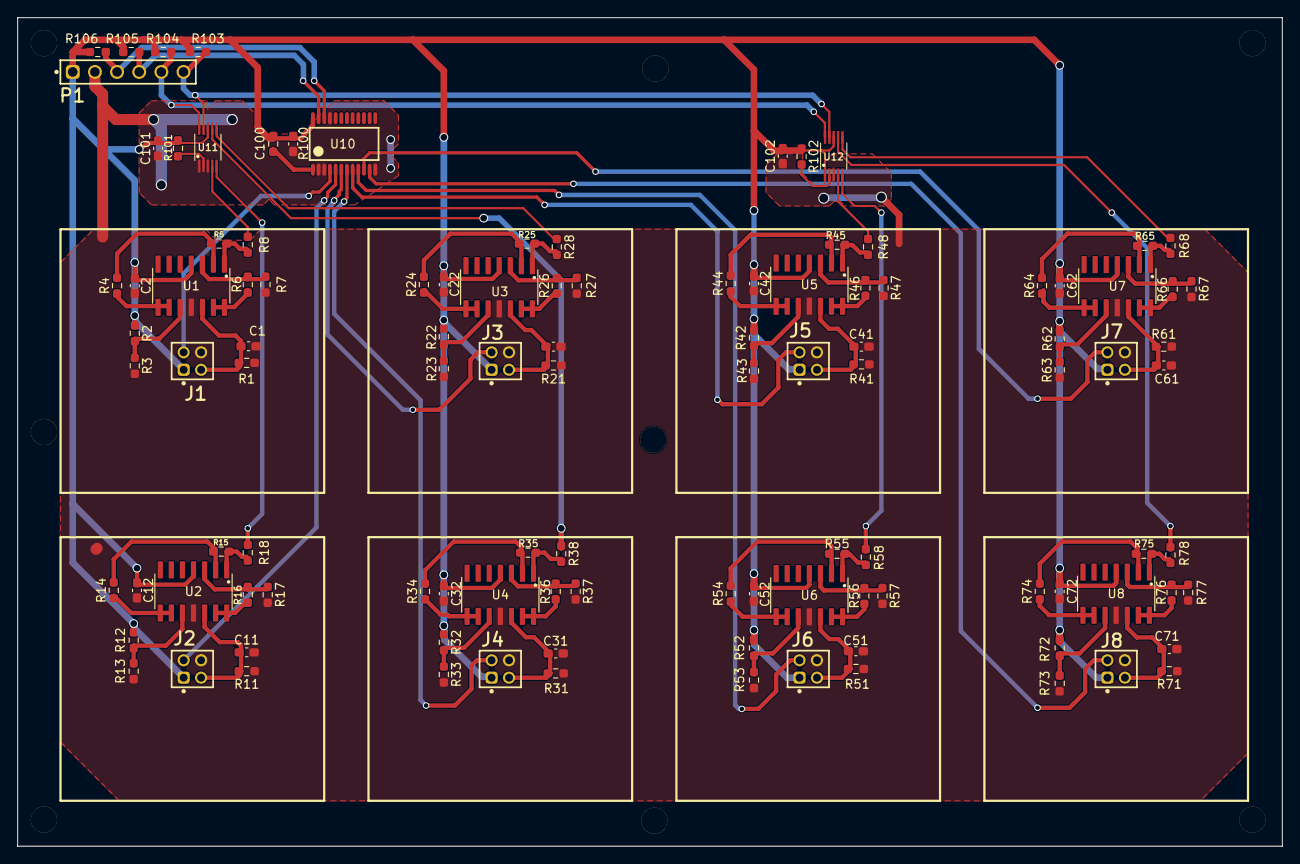
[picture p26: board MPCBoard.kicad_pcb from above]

Board: 2 copper layers, 145.0 x 95.0 mm, 110 parts (0 on the bottom side), 81 nets.

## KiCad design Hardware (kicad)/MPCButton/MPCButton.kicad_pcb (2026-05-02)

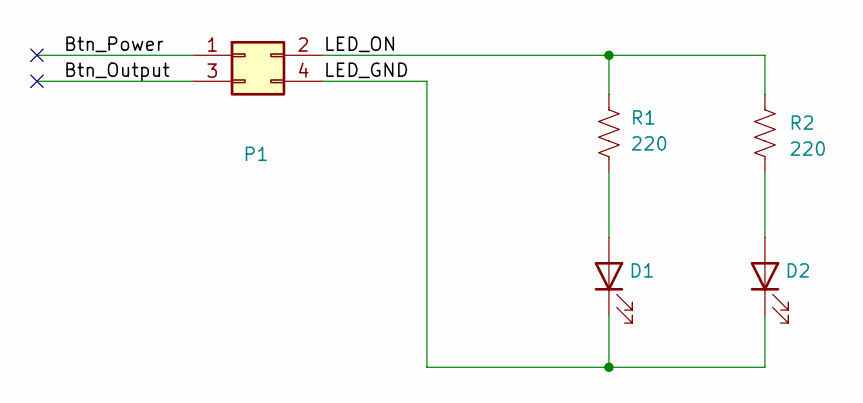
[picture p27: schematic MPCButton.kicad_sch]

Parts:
D1, D2: Red, 2V, 120°; WL-SMCW_0603_150060xx75000; FORWARD VOLTAGE 2V; MANUFACTURER PART NUMBER 150060RS73220
P1: 62100421921; WORKING VOLTAGE 200V; WITHSTANDING VOLTAGE 500V; MANUFACTURER PART NUMBER 62100421921
R1, R2: 220; R_0603_1608Metric_Pad0.98x0.95mm_HandSolder

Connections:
/Btn_Output: P1.3
/Btn_Power: P1.1
/LED_GND: D1.1 (K), D2.1 (K), P1.4
/LED_ON: P1.2, R1.1, R2.1
unnamed: D1.2 (A), R1.2
unnamed: D2.2 (A), R2.2

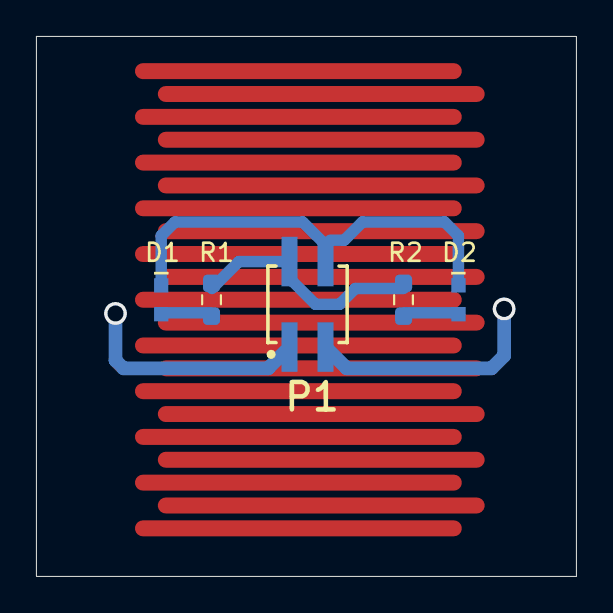
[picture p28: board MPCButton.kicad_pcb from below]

Board: 2 copper layers, 30.0 x 30.0 mm, 5 parts (5 on the bottom side), 4 nets.

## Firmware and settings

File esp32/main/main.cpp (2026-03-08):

#include "freertos/FreeRTOS.h"
#include <driver/i2c_master.h>
#include <graphics/drivers/lcd1602/lcd1602.h>
#include <graphics/drivers/logger/logger.h>
#include <sequencer/sequencer.h>
#include "esp_log.h"
#include "nvs_flash.h"
#include "tinyusb.h"
#include "pads/pads.h"
#include "usb/usb.h"
#include "quantizer/quantizer.h"
#include "selector/selector.h"
#include "screens/screens.h"
#include <graphics/manager/graphics_manager.h>
#include <settings/manager.h>
#include <settings/config/config_component.h>
#include <settings/pads/pads_component.h>
#include <string>
#include <iterator>
#include <sstream>

[[noreturn]] void sequencer_task(void* /*pvParameters*/) {
    const auto& quantizer = Quantizer::instance();
    auto& sequencer = Sequencer::instance();

    while (true) {
        if (ulTaskNotifyTake(pdTRUE, portMAX_DELAY) > 0) {
            if (tud_midi_mounted())
            {
                constexpr uint8_t packet[4] = { 0x0F, 0xF8, 0x00, 0x00 };
                tud_midi_packet_write(packet);
            }

            if (sequencer.enable)
            {
                if (quantizer.ticks == 0) { // new quarter note
                    //handle_step_trigger(quantizer.steps);
                    sequencer.step_trigger_on(quantizer.steps);
                } else if (quantizer.ticks == 5) // end of quarter note
                {
                    sequencer.step_trigger_off(quantizer.steps);
                }
            }
        }
    }
}

[[noreturn]] void drumpad_task(void* /*pvParameters*/)
{
    auto& padsManager = PadsManager::instance();
    pad_midi_event_t value;
    while (true)
    {
        if (xQueueReceive(padsManager.pads_midi_events, &value, portMAX_DELAY) == pdTRUE)
        {
            //ESP_LOGI("DRUMPAD", "%u %u %i", value.channel, value.velocity, value.type);
            //ESP_LOGI("DRUMPAD", "%u %u", value.channel, value.velocity);
            if (tud_midi_mounted() && padsManager.is_enabled)
            {
                if (value.type == NOTE_ON)
                {
                    const uint8_t packet[4] = { 0x09, static_cast<uint8_t>(0x90 | (value.channel & 0x0F)), value.note, value.velocity };
                    tud_midi_packet_write(packet);
                } else
                {
                    const uint8_t packet[4] = { 0x08, static_cast<uint8_t>(0x80 | (value.channel & 0x0F)), value.note, value.velocity };
                    tud_midi_packet_write(packet);
                }
            }
            //vTaskDelay(1);
        }
    }
}

/*
TODO: delete this task
QueueHandle_t settings_updates = nullptr;

void settings_task(void*)
{
    ESP_LOGI("SAMPLER", "Settings Task!");
    auto& settings = SettingsManager::instance();
    auto& quantizer = Quantizer::instance();

    uint32_t update;
    while (true)
    {
        if (xQueueReceive(settings_updates, &update, portMAX_DELAY) == pdTRUE)
        {
            if (update == EVENT_UPDATE_BPM)
            {
                const auto config = settings.get_component<ConfigComponent>("config");
                quantizer.start(config->bpm());
            }
        }
    }
}
*/

static TaskHandle_t vendor_task_h = nullptr;

extern "C" void tud_vendor_rx_cb(uint8_t, const uint8_t*, uint16_t)
{
    if (vendor_task_h)
    {
        xTaskNotifyGive(vendor_task_h);
    }
}

void vendor_respond(std::string string)
{
    string += "\n";

    const char* ptr = string.c_str();
    size_t remaining = string.length();

    while (remaining > 0)
    {
        const size_t available = tud_vendor_write_available();

        if (available > 0)
        {
            const size_t to_send = (remaining < available) ? remaining : available;
            tud_vendor_write(ptr, to_send);

            ptr += to_send;
            remaining -= to_send;

            tud_vendor_write_flush();
        } else
        {
            vTaskDelay(pdMS_TO_TICKS(1));
        }
    }
}

void on_vendor_cmd(const std::vector<std::string>& cmd)
{
    // Make abstract layer for vendor CMDs
    const auto& name = cmd.at(0);
    if (name == "ECHO")
    {
        vendor_respond("ECHO");
        return;
    }

    if (name == "READ_CONFIG")
    {
        if (cmd.size() != 2)
        {
            vendor_respond("invalid args");
            return;
        }

        const auto& component_name = cmd.at(1);
        auto* component = SettingsManager::instance().get_component(component_name);
        if (component == nullptr)
        {
            vendor_respond("invalid component_name");
            return;
        }
        const auto buffer = component->direct_read("");
        vendor_respond(buffer);
        return;
    }

    if (name == "WRITE_CONFIG")
    {
        if (cmd.size() < 3)
        {
            vendor_respond("invalid args");
            return;
        }

        const auto& component_name = cmd.at(1);
        auto* component = SettingsManager::instance().get_component(component_name);
        if (component == nullptr)
        {
            vendor_respond("invalid component_name");
            return;
        }
        auto arg = cmd.at(2);
        std::string buffer;
        if (arg.starts_with("-"))
        {
            arg.erase(0, 1);
            if (cmd.size() < 4)
            {
                vendor_respond("invalid args");
                return;
            }

            for (size_t i = 3; i < cmd.size(); i++)
            {
                buffer += cmd[i];
            }
        } else
        {
            arg = "";
            for (size_t i = 2; i < cmd.size(); i++)
            {
                buffer += cmd[i];
            }
        }
        if (component->direct_write(buffer, arg))
            vendor_respond("Success");
        else
            vendor_respond("Failed");
    }
}

[[noreturn]] void read_vendor_task(void* /*pvParameters*/) {
    vendor_task_h = xTaskGetCurrentTaskHandle();
    uint8_t buffer[64];

    std::string message;

    while (true) {
        ulTaskNotifyTake(pdTRUE, portMAX_DELAY);

        while (tud_vendor_available()) {
            const uint32_t count = tud_vendor_read(buffer, sizeof(buffer));
            if (count == 0) continue;

            message.append(reinterpret_cast<char*>(buffer), count);

            size_t pos;
            while ((pos = message.find('\n')) != std::string::npos)
            {
                std::string cmd = message.substr(0, pos);
                message.erase(0, pos + 1);

                ESP_LOGI("Vendor", "Received: %s", cmd.c_str());

                std::istringstream iss(cmd);
                std::vector results(
                    std::istream_iterator<std::string>{iss},
                    std::istream_iterator<std::string>()
                    );
                on_vendor_cmd(results);
            }
        }
    }
}

extern "C" [[noreturn]] void app_main()
{
    ESP_ERROR_CHECK(nvs_flash_init());
    USB::init();

    vTaskDelay(pdMS_TO_TICKS(2000));

    USB::drain_rx();
    xTaskCreate(
        read_vendor_task,
        "vendor_rx",
        4096,
        nullptr,
        4,
        &vendor_task_h
    );

    auto& settings = SettingsManager::instance();
    if (!settings.init())
    {
        ESP_LOGE("SettingsManager", "Failed to load SettingsManager");
        while (true)
        {
            vTaskDelay(10);
        }
    }

    settings.add_component(std::make_unique<ConfigComponent>());
    settings.add_component(std::make_unique<PadsComponent>());

    //xTaskCreate(settings_task, "settings", 2048, nullptr, 10, nullptr);

    /*
     * I2C bus for:
     *  - LCD
     *  - Buttons' LEDs
     */
    static i2c_master_bus_handle_t i2c_bus_handle = nullptr;
    i2c_master_bus_config_t bus_config = {};
    bus_config.clk_source = I2C_CLK_SRC_DEFAULT;
    bus_config.glitch_ignore_cnt = 7;
    bus_config.i2c_port = I2C_NUM_1;
    bus_config.sda_io_num = GPIO_NUM_21;
    bus_config.scl_io_num = GPIO_NUM_18;
    bus_config.clk_source = I2C_CLK_SRC_DEFAULT;
    bus_config.flags.enable_internal_pullup = true;
    ESP_ERROR_CHECK(i2c_new_master_bus(&bus_config, &i2c_bus_handle));

    //
    auto& quantizer = Quantizer::instance();
    auto& sequencer = Sequencer::instance();
    (void)sequencer;

    auto& padsManager = PadsManager::instance();
    padsManager.init_adc({
        .port_num = I2C_NUM_0,
        .sda_num = GPIO_NUM_12,
        .scl_num = GPIO_NUM_11,
        .adc1_addr = 0x48,
        .adc2_addr = 0x49
    });

    xTaskCreatePinnedToCore(
        sequencer_task,
        "sequencer",
        4096,
        nullptr,
        configMAX_PRIORITIES - 1,
        &quantizer.task_handle,
        1
    );

    xTaskCreatePinnedToCore(
        drumpad_task,
        "drumpad",
        4096,
        nullptr,
        configMAX_PRIORITIES - 1,
        nullptr,
        1
    );

    // Graphics
    GraphicsManager graphics_manager;
    graphics_manager.install_driver(std::make_unique<lcd1602_driver>(i2c_bus_handle, 0x27));
    //graphics_manager.install_driver(std::make_unique<logger_driver>());

    graphics_manager.load_screen("home", create_home_screen);
    graphics_manager.load_screen("settings", create_settings_screen);
    graphics_manager.load_screen("sequencer", create_sequencer_screen);
    graphics_manager.load_screen("pad_settings", create_pad_settings_screen);

    graphics_manager.navigate("home");

    // Hardware inputs
    QueueHandle_t selector_events = xQueueCreate(10, sizeof(selector_event_t));
    selector_config_t selector_config = {
        .clk_gpio = GPIO_NUM_8,
        .data_gpio = GPIO_NUM_7,
        .btn_gpio = GPIO_NUM_9,
        .events = selector_events
    };
    Selector selector(&selector_config);
    (void)selector;

    /* Graphics task */
    QueueSetHandle_t graphics_inputs_events = xQueueCreateSet(10 + 64);

    xQueueAddToSet(selector_events, graphics_inputs_events);
    xQueueAddToSet(padsManager.pads_input_events, graphics_inputs_events);

    padsManager.start_task();

    selector_event_t selector_event;
    pad_input_event_t pad_input_event;

    uint32_t press_start_time = 0;
    uint32_t pads_press_start_time[8] = {};

    graphics_manager.update();
    while (true)
    {
        constexpr uint32_t LONG_PRESS_THRESHOLD_MS = 500;
        QueueSetMemberHandle_t input = xQueueSelectFromSet(graphics_inputs_events, portMAX_DELAY);

        if (input == selector_events)
        {
            xQueueReceive(selector_events, &selector_event, 0);

            switch (selector_event)
            {
            case ROTATION_LEFT:
                graphics_manager.send_event(EVENT_SCROLL_LEFT);
                break;
            case ROTATION_RIGHT:
                graphics_manager.send_event(EVENT_SCROLL_RIGHT);
                break;
            case BUTTON_PRESSED:
                press_start_time = esp_log_timestamp();
                break;
            case BUTTON_RELEASED:
                {
                    const uint32_t duration = esp_log_timestamp() - press_start_time;

                    if (duration >= LONG_PRESS_THRESHOLD_MS)
                    {
                        graphics_manager.send_event(EVENT_BACK);
                    } else
                    {
                        graphics_manager.send_event(EVENT_CLICK);
                    }
                } break;
            default:
                break;
            }
        } else if (input == padsManager.pads_input_events)
        {
            xQueueReceive(padsManager.pads_input_events, &pad_input_event, 0);

            const auto pad_index = pad_input_event.pad_index;

            if (pad_input_event.pressed)
            {
                pads_press_start_time[pad_index] = esp_log_timestamp();
                continue;
            } else
            {
                const uint32_t duration = esp_log_timestamp() - pads_press_start_time[pad_index];
                uint32_t custom_event = 0 | (pad_index & 0b111);

                if (duration >= LONG_PRESS_THRESHOLD_MS)
                {
                    custom_event |= (1 << 3);
                }
                if (!graphics_manager.send_custom_event(custom_event))
                    continue;
            }
        }

        graphics_manager.update();
        /*
        TODO: delete this code
        QueueSetMemberHandle_t input = xQueueSelectFromSet(graphics_inputs_events, portMAX_DELAY);

        if (input == selector_events)
        {
            xQueueReceive(selector_events, &selector_event, 0);

            if (selector_event == ROTATION_LEFT)
                lcd.action_left();
            else if (selector_event == ROTATION_RIGHT)
                lcd.action_right();
            else if (selector_event == BUTTON_PRESSED)
            {
                press_start_time = esp_log_timestamp();
            } else if (selector_event == BUTTON_RELEASED)
            {
                const uint32_t duration = esp_log_timestamp() - press_start_time;

                if (duration >= LONG_PRESS_THRESHOLD_MS)
                {
                    lcd.action_long_click();
                } else
                {
                    lcd.action_click();
                }
            }
        }
        else if (input == padsManager.pads_input_events)
        {
            xQueueReceive(padsManager.pads_input_events, &pad_input_event, 0);

            const auto channel = pad_input_event.channel;

            if (pad_input_event.pressed)
            {
                pads_press_start_time[channel] = esp_log_timestamp();
                continue;
            } else
            {
                const uint32_t duration = esp_log_timestamp() - pads_press_start_time[channel];
                uint32_t custom_event = 0 | (channel & 0b111);

                if (duration >= LONG_PRESS_THRESHOLD_MS)
                {
                    custom_event |= (1 << 3);
                }
                if (!lcd.custom_event(custom_event))
                    continue;
            }
        }

        lcd.render();*/
    }
}

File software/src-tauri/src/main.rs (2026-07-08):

// Prevents additional console window on Windows in release, DO NOT REMOVE!!
#![cfg_attr(not(debug_assertions), windows_subsystem = "windows")]

use cpal::traits::{DeviceTrait, HostTrait};
use std::path::Path;
use std::sync::{Arc, Mutex};
use std::{fs, thread};
use std::io::Write;
use serde::{Deserialize, Serialize};
use tauri::{Emitter, State};

use software_sampler_lib::audio::{create_audio_stream, load_and_decode, AudioData, AudioFile, AudioTrack};
use software_sampler_lib::drumpad::PadConfig;
use software_sampler_lib::midi::{create_midi_task, MIDIEvent};
use software_sampler_lib::handlers::*;
use software_sampler_lib::AppState;

#[derive(Serialize)]
struct MainConfig {
    midi_device: String
}

fn init_configurations() {
    let config = MainConfig {
        midi_device: "MIDI Device".to_string()
    };
    if let Ok(mut file) = fs::File::create("test.json") {
        file.write_all(serde_json::to_string_pretty(&config).unwrap().as_bytes()).ok();
    }
}

fn main() {
    let samples = load_and_decode(Path::new("/home/edoar/Projects/software-sampler/samples/kick.wav"));
    let samples2 = load_and_decode(Path::new("/home/edoar/RustroverProjects/SoftwareSampler/target/debug/samples/sample2.wav"));
    let samples3 = load_and_decode(Path::new("/home/edoar/RustroverProjects/SoftwareSampler/target/debug/samples/sample3.wav"));

    let audio_data2 = AudioData {
        track: AudioTrack {
            label: "kick".to_string(),
            id: 1,
        },
        file: samples,
    };
    let audio_data3 = AudioData {
        track: AudioTrack {
            label: "snare".to_string(),
            id: 2,
        },
        file: samples2
    };
    let audio_data4 = AudioData {
        track: AudioTrack {
            label: "idk".to_string(),
            id: 3,
        },
        file: samples3
    };

    let mut audio_data: Vec<Arc<AudioData>> = vec![];

    audio_data.push(Arc::new(audio_data2));
    audio_data.push(Arc::new(audio_data3));
    audio_data.push(Arc::new(audio_data4));

    let audio_data = Arc::new(audio_data);

    let pad_configs = Arc::new(Mutex::new([PadConfig::default(); 8]));

    {
        let mut guard = pad_configs.lock().unwrap();
        for (index, config) in guard.iter_mut().enumerate() {
            config.id = (index + 1) as u8;
            config.note = 60 + index as u8;
        }

        guard[0].track_id = 1;
        guard[1].track_id = 2;
        guard[2].track_id = 3;
    }

    let events_rx = create_midi_task();

    let hosts = cpal::available_hosts();
    for host in hosts {
        println!("Available Host: {}", host.name());
    }

    let host = cpal::host_from_id(cpal::HostId::Jack).expect("Jack host");
    println!("Host: {}", host.id());
    let device = host.default_output_device().expect("No output device found");
    println!("Connected to virtual device: {:?}", device.id());

    let audio_cmd_tx = create_audio_stream(device);

    tauri::Builder::default()
        .manage(AppState {
            audio_data: audio_data.clone(),
            pad_configs: pad_configs.clone(),
        })
        .setup(move |app| {
            let app_handle = app.handle().clone();

            let pad_configs = pad_configs.clone();
            {
                let audio_data = audio_data.clone();
                let app_handle = app_handle.clone();

                thread::spawn(move || {
                    loop {
                        if let Ok(event) = events_rx.try_recv() {
                            match event {
                                MIDIEvent::NoteOn(note, velocity) => {
                                    let configs: Vec<PadConfig> = {
                                        let guard = pad_configs.lock().unwrap();
                                        guard.iter()
                                            .filter(|item| item.note == note)
                                            .cloned()
                                            .collect()
                                    };
                                    //let mut guard = playback_states.lock().unwrap();
                                    for config in configs.iter() {
                                        app_handle.emit("pad-event", (config.id, true)).unwrap();

                                        if let Some(matched_audio) = audio_data.iter()
                                            .find(|item| item.track.id == config.track_id) {
                                            let _ = audio_cmd_tx.send(matched_audio.clone());
                                        }
                                    }
                                }
                                MIDIEvent::NoteOff(note) => {
                                    let configs: Vec<PadConfig> = {
                                        let guard = pad_configs.lock().unwrap();
                                        guard.iter()
                                            .filter_map(|item| {
                                                if item.note == note {
                                                    Some(item.clone())
                                                } else {
                                                    None
                                                }
                                            })
                                            .collect()
                                    };
                                    //let mut guard = playback_states.lock().unwrap();
                                    for config in configs.iter() {
                                        app_handle.emit("pad-event", (config.id, false)).unwrap();
                                    }
                                }
                            }
                        }
                    }
                });
            }

            Ok(())
        })
        .plugin(tauri_plugin_opener::init())
        .invoke_handler(tauri::generate_handler![
            get_pad_configs, set_pad_configs,
            get_tracks,
            get_audio_file
        ])
        .run(tauri::generate_context!())
        .expect("error while running tauri application");
}

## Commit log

2026-03-08 fix vendor_respond and sequencer pad numbers
    [main.cpp, pads.cpp]
2026-03-26 migrating to esp32-rust
2026-04-01 rust settings_manager and screens
    [partitions.csv]
2026-04-05 adding sequencer and shortcuts
    [lib.rs]
2026-04-24 sequencer features and bug fixes
    [lib.rs, main.cpp]
2026-04-24 removed 3d models
    [MPCButton.stl]
2026-05-02 fix kicad projects
    [MPCBoard.kicad_pcb, MPCBoard.kicad_sch, MPCButton.kicad_pcb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]

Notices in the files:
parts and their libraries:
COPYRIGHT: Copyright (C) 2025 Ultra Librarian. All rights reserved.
